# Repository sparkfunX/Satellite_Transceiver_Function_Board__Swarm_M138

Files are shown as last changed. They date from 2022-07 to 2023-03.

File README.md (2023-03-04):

SparkX Satellite Transceiver Function Board - Swarm M138
========================================

<p align="center">
  <a href="https://github.com/sparkfunX/Satellite_Transceiver_Function_Board__Swarm_M138/issues" alt="Issues">
    </a>
  <a href="https://github.com/sparkfunX/Satellite_Transceiver_Function_Board__Swarm_M138/actions" alt="Actions">
    </a>
  <a href="https://github.com/sparkfunX/Satellite_Transceiver_Function_Board__Swarm_M138/blob/main/LICENSE.md" alt="License">
    </a>
  <a href="https://twitter.com/intent/follow?screen_name=sparkfun">
    </a>
</p>

SparkX Satellite Transceiver Function Board - Swarm M138 (https://www.sparkfun.com/products/20107)

*[SparkX Satellite Transceiver Function Board - Swarm M138 (SPX-20107)](https://www.sparkfun.com/products/20107)*

The [SparkX Satellite Transceiver Function Board - Swarm M138 (SPX-20107)](https://www.sparkfun.com/products/20107) is an adapter which allows you to add Swarm Satellite connectivity
to your [MicroMod](https://www.sparkfun.com/micromod) project. It is designed to be plugged into the [MicroMod Main Board - Single](https://www.sparkfun.com/products/18575)
or [MicroMod Main Board - Double](https://www.sparkfun.com/products/18575). You can then install the Swarm M138 satellite modem and communicate using our dedicated 
[Swarm Satellite Arduino Library](https://github.com/sparkfun/SparkFun_Swarm_Satellite_Arduino_Library).

**Please note: the Swarm M138 modem is not included with the function board.** You will need to purchase the [Satellite Transceiver Breakout - Swarm M138 (SPX-19236)](https://www.sparkfun.com/products/19236)
separately to obtain the modem, antenna and ground plane.

Repository Contents
-------------------

* **[/docs](/docs/)** - Online documentation files
    * [board_files](/docs/board_files/) - Files for the product design
        * [Eagle design files](/docs/board_files/Satellite_Transceiver_Function_Board__Swarm_M138_x04.zip) (.zip)
        * [Schematic](/docs/board_files/Schematic.pdf) (.pdf)
        * [Dimensions](/docs/board_files/Dimensions.png) (.png)
    * [img/hookup_guide/](/docs/img/hookup_guide/) - Images for hookup guide documentation
* **[/Hardware](/Hardware/)** - Eagle design files (.brd, .sch)

Documentation
--------------
* **[Hookup Guide (mkdocs)](https://sparkfunx.github.io/Satellite_Transceiver_Function_Board__Swarm_M138/)** - Hookup guide for the SparkX Satellite Transceiver Function Board - Swarm M138 hosted by GitHub pages.

Product Versions
----------------
* [SPX-20107](https://www.sparkfun.com/products/20107) - Initial SparkX Release

License Information
-------------------

This product is _**open source**_! 

Please review the LICENSE.md file for license information. 

If you have any questions or concerns on licensing, please contact technical support on our [SparkFun forums](https://forum.sparkfun.com/viewforum.php?f=152).

Distributed as-is; no warranty is given.

- Your friends at SparkFun.

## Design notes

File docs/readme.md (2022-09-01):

This folder contains the assets and markdown files for the [SparkX Satellite Transceiver Function Board - Swarm M138 - Product Manual](https://sparkfunx.github.io/Satellite_Transceiver_Function_Board__Swarm_M138/) that are rendered with [mkdocs](https://www.mkdocs.org/).

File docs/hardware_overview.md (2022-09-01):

## Overview

The SparkX Satellite Transceiver Function Board - Swarm M138 is quite a simple board. The following is a summary of its features and functions:

* **`Power`** - Power for the Swarm M138 modem is drawn from the MicroMod **VCC** pins
    * The modem requires 3.0V<sub>Min</sub>, 5.0V<sub>Max</sub>
    * **VCC** will be 5.0V when the MicroMod Main Board is powered via USB-C
    * **VCC** will be between 3.6V and 4.2V when the MicroMod Main Board is drawing power from a LiPo battery
* **`High-Side Power Switch`** - Power for the Swarm M138 modem is connected via a MIC94064 High-Side Power Switch
    * By default, the modem power is turned off
    * Modem power can be enabled by pulling the **PWR_EN** pin high
        * **PWR_EN** is connected to the MicroMod Processor - the exact pin depends on which Main Board and Processor Board are being used. See the [table below](#example-pin-connection-table) for example pins
    * Modem power can be disabled by pulling the **PWR_EN** pin low or leaving it unconnected
    * The **EN** split pad jumper can be soldered closed to permanently enable modem power
* **`TX and RX`** - The M138 modem uses 3.3V serial (UART) to communicate at 115200 baud (8 data bits, 1 stop bit, no parity)
    * **TXO** and **RXI** are connected to UART pins on the MicroMod Processor
* **`GPIO1`** - The modem's **GPIO1** pin can perform several functions
    * **GPIO1** is connected to a GPIO pin on the MicroMod Processor - the exact pin depends on which Main Board and Processor Board are being used. See the [table below](#example-pin-connection-table) for example pins
    * **GPIO1** can be configured as a "wake from sleep mode" input
    * **GPIO1** can be configured as a "unread messages", "unsent messages" or "sleep mode active" output
    * When configured as an output, **GPIO1** is "open drain". A configurable pull-up resistor provides the high logic level
* **`TX/RX`** - The modem's TX/RX pin indicates if the modem is transmitting or receiving
    * **TX/RX** is connected to a GPIO pin on the MicroMod Processor - the exact pin depends on which Main Board and Processor Board are being used. See the [table below](#example-pin-connection-table) for example pins
    * **TX/RX** is high when the modem is transmitting, low when receiving
* **`EEPROM`** - Like all MicroMod Function Boards, a small EEPROM is provided
    * The Processor Board can read the EEPROM to discover which Function Boards are connected

## Board Images

<center>
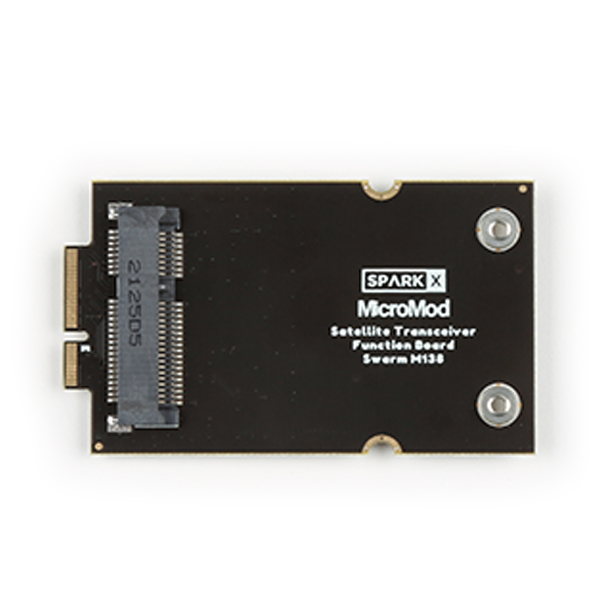
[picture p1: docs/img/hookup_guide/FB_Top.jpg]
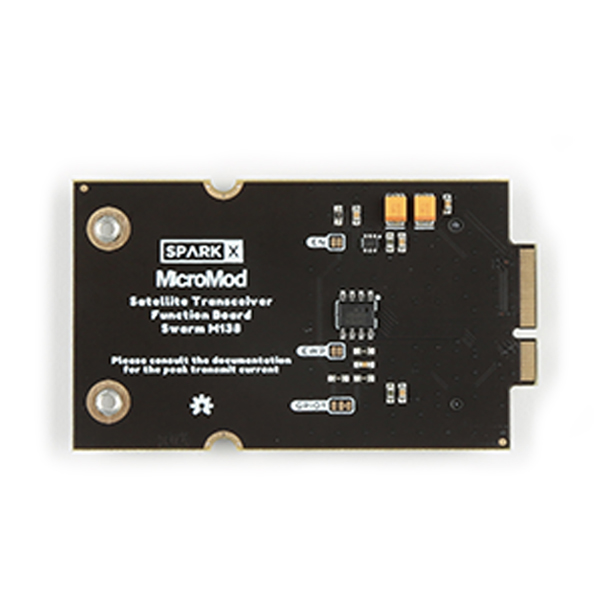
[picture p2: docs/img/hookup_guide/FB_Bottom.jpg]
  <br>
*Board images. (Click to enlarge)*
</center>

## Board Dimensions

The board dimensions are illustrated in the drawing below. The listed measurements are in mm. The two mounting holes and two stand-offs are compatible with M2.5 screws.

<center>
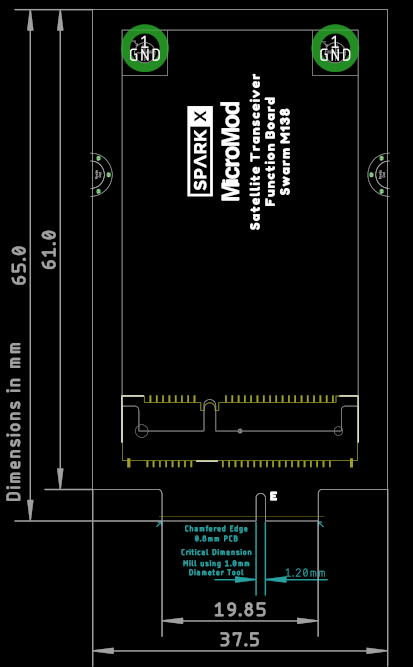
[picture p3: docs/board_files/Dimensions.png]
Board Dimensions
<br>
*Board dimensions. (Click to enlarge)*
</center>

## M.2 Connector Pinout

The pinout of the function board's M.2 edge connector (gold fingers) is defined in the following table.

Note that the M.2 connector pins on opposing sides are offset from each other as indicated by the bottom pins where it says "(Not Connected)".

There is no connection to pins that have a "-" under the primary function.

<table style="font-size:12.25px; width:100%">
    <tr>
        <th colspan="2" style="text-align:center; vertical-align:middle; min-width:2rem;" width="40.0%">
            Function
        </th>
        <th style="text-align:center; vertical-align:middle; min-width:1rem;" width="10.0%">
            Bottom<br>
            Pin
        </th>
        <th style="text-align:center; vertical-align:middle; min-width:1rem;" width="10.0%">
            Top<br>
            Pin
        </th>
        <th colspan="2" style="text-align:center; vertical-align:middle; min-width:2rem;" width="40.0%">
            Function
        </th>
    </tr>
    <tr>
        <td style="vertical-align:middle" align="center"></td>
        <td style="vertical-align:middle" align="center">(Not<br>Connected)</td>
        <td style="vertical-align:middle" align="center"></td>
        <td style="vertical-align:middle" align="center"><b>75</b></td>
        <td style="vertical-align:middle" align="center" bgcolor="#0000000"><font style="color: white; background: black;">GND</font></td>
        <td style="vertical-align:middle" align="center"></td>
    </tr>
    <tr>
        <td style="vertical-align:middle" align="center"></td>
        <td style="vertical-align:middle" align="center" bgcolor="#ea4335">VCC</td>
        <td style="vertical-align:middle" align="center"><b>74</b></td>
        <td style="vertical-align:middle" align="center"><b>73</b></td>
        <td style="vertical-align:middle" align="center" bgcolor="#ea4335">3.3V</td>
        <td style="vertical-align:middle" align="center"></td>
    </tr>
    <tr>
        <td style="vertical-align:middle" align="center"></td>
        <td style="vertical-align:middle" align="center" bgcolor="#ea4335">VCC</td>
        <td style="vertical-align:middle" align="center"><b>72</b></td>
        <td style="vertical-align:middle" align="center"><b>71</b></td>
        <td style="vertical-align:middle" align="center" bgcolor="#ea4335">PWR_EN</td>
        <td style="vertical-align:middle" align="center"><b>Power Enable</b><br>Pull high to<br>enable power</td>
    </tr>
    <tr>
        <td style="vertical-align:middle" align="center"></td>
        <td style="vertical-align:middle" align="center">-</td>
        <td style="vertical-align:middle" align="center"><b>70</b></td>
        <td style="vertical-align:middle" align="center"><b>69</b></td>
        <td style="vertical-align:middle" align="center">-</td>
        <td style="vertical-align:middle" align="center"></td>
    </tr>
    <tr>
        <td style="vertical-align:middle" align="center"></td>
        <td style="vertical-align:middle" align="center">-</td>
        <td style="vertical-align:middle" align="center"><b>68</b></td>
        <td style="vertical-align:middle" align="center"><b>67</b></td>
        <td style="vertical-align:middle" align="center">-</td>
        <td style="vertical-align:middle" align="center"></td>
    </tr>
    <tr>
        <td style="vertical-align:middle" align="center"></td>
        <td style="vertical-align:middle" align="center">-</td>
        <td style="vertical-align:middle" align="center"><b>66</b></td>
        <td style="vertical-align:middle" align="center"><b>65</b></td>
        <td style="vertical-align:middle" align="center">-</td>
        <td style="vertical-align:middle" align="center"></td>
    </tr>
    <tr>
        <td style="vertical-align:middle" align="center"></td>
        <td style="vertical-align:middle" align="center">-</td>
        <td style="vertical-align:middle" align="center"><b>64</b></td>
        <td style="vertical-align:middle" align="center"><b>63</b></td>
        <td style="vertical-align:middle" align="center">-</td>
        <td style="vertical-align:middle" align="center"></td>
    </tr>
    <tr>
        <td style="vertical-align:middle" align="center"></td>
        <td style="vertical-align:middle" align="center">-</td>
        <td style="vertical-align:middle" align="center"><b>62</b></td>
        <td style="vertical-align:middle" align="center"><b>61</b></td>
        <td style="vertical-align:middle" align="center">-</td>
        <td style="vertical-align:middle" align="center"></td>
    </tr>
    <tr>
        <td style="vertical-align:middle" align="center"></td>
        <td style="vertical-align:middle" align="center">-</td>
        <td style="vertical-align:middle" align="center"><b>60</b></td>
        <td style="vertical-align:middle" align="center"><b>59</b></td>
        <td style="vertical-align:middle" align="center">-</td>
        <td style="vertical-align:middle" align="center"></td>
    </tr>
    <tr>
        <td style="vertical-align:middle" align="center"></td>
        <td style="vertical-align:middle" align="center">-</td>
        <td style="vertical-align:middle" align="center"><b>58</b></td>
        <td style="vertical-align:middle" align="center"><b>57</b></td>
        <td style="vertical-align:middle" align="center">-</td>
        <td style="vertical-align:middle" align="center"></td>
    </tr>
    <tr>
        <td style="vertical-align:middle" align="center"></td>
        <td style="vertical-align:middle" align="center">-</td>
        <td style="vertical-align:middle" align="center"><b>56</b></td>
        <td style="vertical-align:middle" align="center"><b>55</b></td>
        <td style="vertical-align:middle" align="center">-</td>
        <td style="vertical-align:middle" align="center"></td>
    </tr>
    <tr>
        <td style="vertical-align:middle" align="center"></td>
        <td style="vertical-align:middle" align="center">-</td>
        <td style="vertical-align:middle" align="center"><b>54</b></td>
        <td style="vertical-align:middle" align="center"><b>53</b></td>
        <td style="vertical-align:middle" align="center">TX/RX</td>
        <td style="vertical-align:middle" align="center"><b>Modem State</b><br>Transmit (High)<br>Receive (Low)</td>
    </tr>
    <tr>
        <td style="vertical-align:middle" align="center"></td>
        <td style="vertical-align:middle" align="center">-</td>
        <td style="vertical-align:middle" align="center"><b>52</b></td>
        <td style="vertical-align:middle" align="center"><b>51</b></td>
        <td style="vertical-align:middle" align="center">-</td>
        <td style="vertical-align:middle" align="center"></td>
    </tr>
    <tr>
        <td style="vertical-align:middle" align="center"></td>
        <td style="vertical-align:middle" align="center">-</td>
        <td style="vertical-align:middle" align="center"><b>50</b></td>
        <td style="vertical-align:middle" align="center"><b>49</b></td>
        <td style="vertical-align:middle" align="center">-</td>
        <td style="vertical-align:middle" align="center"></td>
    </tr>
    <tr>
        <td style="vertical-align:middle" align="center"></td>
        <td style="vertical-align:middle" align="center">-</td>
        <td style="vertical-align:middle" align="center"><b>48</b></td>
        <td style="vertical-align:middle" align="center"><b>47</b></td>
        <td style="vertical-align:middle" align="center">GPIO1</td>
        <td style="vertical-align:middle" align="center"><b>Modem GPIO1</b><br>I/O pin</td>
    </tr>
    <tr>
        <td style="vertical-align:middle" align="center"></td>
        <td style="vertical-align:middle" align="center">-</td>
        <td style="vertical-align:middle" align="center"><b>46</b></td>
        <td style="vertical-align:middle" align="center"><b>45</b></td>
        <td style="vertical-align:middle" align="center" bgcolor="#0000000"><font style="color: white; background: black;">GND</font></td>
        <td style="vertical-align:middle" align="center"></td>
    </tr>
    <tr>
        <td style="vertical-align:middle" align="center"></td>
        <td style="vertical-align:middle" align="center">-</td>
        <td style="vertical-align:middle" align="center"><b>44</b></td>
        <td style="vertical-align:middle" align="center"><b>43</b></td>
        <td style="vertical-align:middle" align="center">-</td>
        <td style="vertical-align:middle" align="center"></td>
    </tr>
    <tr>
        <td style="vertical-align:middle" align="center"></td>
        <td style="vertical-align:middle" align="center">-</td>
        <td style="vertical-align:middle" align="center"><b>42</b></td>
        <td style="vertical-align:middle" align="center"><b>41</b></td>
        <td style="vertical-align:middle" align="center">-</td>
        <td style="vertical-align:middle" align="center"></td>
    </tr>
    <tr>
        <td style="vertical-align:middle" align="center">Write Protect</td>
        <td style="vertical-align:middle" align="center">EEPROM WP</td>
        <td style="vertical-align:middle" align="center"><b>40</b></td>
        <td style="vertical-align:middle" align="center"><b>39</b></td>
        <td style="vertical-align:middle" align="center" bgcolor="#0000000"><font style="color: white; background: black;">GND</font></td>
        <td style="vertical-align:middle" align="center"></td>
    </tr>
    <tr>
        <td style="vertical-align:middle" align="center"></td>
        <td style="vertical-align:middle" align="center">-</td>
        <td style="vertical-align:middle" align="center"><b>38</b></td>
        <td style="vertical-align:middle" align="center"><b>37</b></td>
        <td style="vertical-align:middle" align="center">-</td>
        <td style="vertical-align:middle" align="center"></td>
    </tr>
    <tr>
        <td style="vertical-align:middle" align="center"></td>
        <td style="vertical-align:middle" align="center">EEPROM A0</td>
        <td style="vertical-align:middle" align="center"><b>36</b></td>
        <td style="vertical-align:middle" align="center"><b>35</b></td>
        <td style="vertical-align:middle" align="center">-</td>
        <td style="vertical-align:middle" align="center"></td>
    </tr>
    <tr>
        <td style="vertical-align:middle" align="center"></td>
        <td style="vertical-align:middle" align="center">EEPROM A1</td>
        <td style="vertical-align:middle" align="center"><b>34</b></td>
        <td style="vertical-align:middle" align="center"><b>33</b></td>
        <td style="vertical-align:middle" align="center" bgcolor="#0000000"><font style="color: white; background: black;">GND</font></td>
        <td style="vertical-align:middle" align="center"></td>
    </tr>
    <tr>
        <td style="vertical-align:middle" align="center"></td>
        <td style="vertical-align:middle" align="center">EEPROM A2</td>
        <td style="vertical-align:middle" align="center"><b>32</b></td>
        <td style="vertical-align:middle" align="center"><b>31</b></td>
        <td style="vertical-align:middle" align="center">Module Key</td>
        <td style="vertical-align:middle" align="center"></td>
    </tr>
    <tr>
        <td style="vertical-align:middle" align="center"></td>
        <td style="vertical-align:middle" align="center">Module Key</td>
        <td style="vertical-align:middle" align="center"><b>30</b></td>
        <td style="vertical-align:middle" align="center"><b>29</b></td>
        <td style="vertical-align:middle" align="center">Module Key</td>
        <td style="vertical-align:middle" align="center"></td>
    </tr>
    <tr>
        <td style="vertical-align:middle" align="center"></td>
        <td style="vertical-align:middle" align="center">Module Key</td>
        <td style="vertical-align:middle" align="center"><b>28</b></td>
        <td style="vertical-align:middle" align="center"><b>27</b></td>
        <td style="vertical-align:middle" align="center">Module Key</td>
        <td style="vertical-align:middle" align="center"></td>
    </tr>
    <tr>
        <td style="vertical-align:middle" align="center"></td>
        <td style="vertical-align:middle" align="center">Module Key</td>
        <td style="vertical-align:middle" align="center"><b>26</b></td>
        <td style="vertical-align:middle" align="center"><b>25</b></td>
        <td style="vertical-align:middle" align="center">Module Key</td>
        <td style="vertical-align:middle" align="center"></td>
    </tr>
    <tr>
        <td style="vertical-align:middle" align="center"></td>
        <td style="vertical-align:middle" align="center">Module Key</td>
        <td style="vertical-align:middle" align="center"><b>24</b></td>
        <td style="vertical-align:middle" align="center"><b>23</b></td>
        <td style="vertical-align:middle" align="center">-</td>
        <td style="vertical-align:middle" align="center"></td>
    </tr>
    <tr>
        <td style="vertical-align:middle" align="center"></td>
        <td style="vertical-align:middle" align="center">-</td>
        <td style="vertical-align:middle" align="center"><b>22</b></td>
        <td style="vertical-align:middle" align="center"><b>21</b></td>
        <td style="vertical-align:middle" align="center">EEPROM SCL</td>
        <td style="vertical-align:middle" align="center"></td>
    </tr>
    <tr>
        <td style="vertical-align:middle" align="center"></td>
        <td style="vertical-align:middle" align="center">-</td>
        <td style="vertical-align:middle" align="center"><b>20</b></td>
        <td style="vertical-align:middle" align="center"><b>19</b></td>
        <td style="vertical-align:middle" align="center">EEPROM SDA</td>
        <td style="vertical-align:middle" align="center"></td>
    </tr>
    <tr>
        <td style="vertical-align:middle" align="center"></td>
        <td style="vertical-align:middle" align="center">-</td>
        <td style="vertical-align:middle" align="center"><b>18</b></td>
        <td style="vertical-align:middle" align="center"><b>17</b></td>
        <td style="vertical-align:middle" align="center">-</td>
        <td style="vertical-align:middle" align="center"></td>
    </tr>
    <tr>
        <td style="vertical-align:middle" align="center"></td>
        <td style="vertical-align:middle" align="center">-</td>
        <td style="vertical-align:middle" align="center"><b>16</b></td>
        <td style="vertical-align:middle" align="center"><b>15</b></td>
        <td style="vertical-align:middle" align="center" bgcolor="#4285f4">RXI</td>
        <td style="vertical-align:middle" align="center">Modem UART In</td>
    </tr>
    <tr>
        <td style="vertical-align:middle" align="center"></td>
        <td style="vertical-align:middle" align="center">-</td>
        <td style="vertical-align:middle" align="center"><b>14</b></td>
        <td style="vertical-align:middle" align="center"><b>13</b></td>
        <td style="vertical-align:middle" align="center" bgcolor="#4285f4">TXO</td>
        <td style="vertical-align:middle" align="center">Modem UART Out</td>
    </tr>
    <tr>
        <td style="vertical-align:middle" align="center"></td>
        <td style="vertical-align:middle" align="center">-</td>
        <td style="vertical-align:middle" align="center"><b>12</b></td>
        <td style="vertical-align:middle" align="center"><b>11</b></td>
        <td style="vertical-align:middle" align="center">-</td>
        <td style="vertical-align:middle" align="center"></td>
    </tr>
    <tr>
        <td style="vertical-align:middle" align="center"></td>
        <td style="vertical-align:middle" align="center">-</td>
        <td style="vertical-align:middle" align="center"><b>10</b></td>
        <td style="vertical-align:middle" align="center"><b>9</b></td>
        <td style="vertical-align:middle" align="center">-</td>
        <td style="vertical-align:middle" align="center"></td>
    </tr>
    <tr>
        <td style="vertical-align:middle" align="center"></td>
        <td style="vertical-align:middle" align="center" bgcolor="#0000000"><font style="color: white; background: black;">GND</font></td>
        <td style="vertical-align:middle" align="center"><b>8</b></td>
        <td style="vertical-align:middle" align="center"><b>7</b></td>
        <td style="vertical-align:middle" align="center">-</td>
        <td style="vertical-align:middle" align="center"></td>
    </tr>
    <tr>
        <td style="vertical-align:middle" align="center"></td>
        <td style="vertical-align:middle" align="center">-</td>
        <td style="vertical-align:middle" align="center"><b>6</b></td>
        <td style="vertical-align:middle" align="center"><b>5</b></td>
        <td style="vertical-align:middle" align="center">-</td>
        <td style="vertical-align:middle" align="center"></td>
    </tr>
    <tr>
        <td style="vertical-align:middle" align="center"></td>
        <td style="vertical-align:middle" align="center">-</td>
        <td style="vertical-align:middle" align="center"><b>4</b></td>
        <td style="vertical-align:middle" align="center"><b>3</b></td>
        <td style="vertical-align:middle" align="center">-</td>
        <td style="vertical-align:middle" align="center"></td>
    </tr>
    <tr>
        <td style="vertical-align:middle" align="center"></td>
        <td style="vertical-align:middle" align="center" bgcolor="#0000000"><font style="color: white; background: black;">GND</font></td>
        <td style="vertical-align:middle" align="center"><b>2</b></td>
        <td style="vertical-align:middle" align="center"><b>1</b></td>
        <td style="vertical-align:middle" align="center" bgcolor="#0000000"><font style="color: white; background: black;">GND</font></td>
        <td style="vertical-align:middle" align="center"></td>
    </tr>
</table>

*For more details, users can reference the [schematic](./board_files/Schematic.pdf).*

## Example Pin Connection Table

The pin connections depend on which [MicroMod](https://www.sparkfun.com/micromod) Main Board and Processor Board are being used.

The table below provides an example for the [Artemis Processor Board](https://www.sparkfun.com/products/16401) and the [Main Board - Double](https://www.sparkfun.com/products/18576).

<table  style="font-size:12.25px;width:100%">
    <tr>
        <th rowspan="2" style="text-align:center; vertical-align:middle; min-width:2rem;" width="40.0%">
            Satellite Function Board<br>
            Pin Name
        </th>
        <th rowspan="2" style="text-align:center; vertical-align:middle; min-width:1rem;" width="20.0%">
            Processor<br>
            I/O<br>
            Direction
        </th>
        <th colspan="2" style="text-align:center; vertical-align:middle;min-width:2rem;" width="40.0%">
            Main Board's<br>
            Processor Pin
        </th>
    </tr>
    <tr>
        <th style="text-align:center; vertical-align:middle; min-width:1rem;" width="20.0%">
            Slot 0
        </th>
        <th style="text-align:center; vertical-align:middle; min-width:1rem;" width="20.0%">
            Slot 1
        </th>
    </tr>
    <tr>
        <td style="vertical-align:middle" align="center" bgcolor="#ea4335">VCC</td>
        <td style="vertical-align:middle" align="center">Power</td>
        <td style="vertical-align:middle" align="center" bgcolor="#ea4335">VCC</td>
        <td style="vertical-align:middle" align="center" bgcolor="#ea4335">VCC</td>
    </tr>
    <tr>
        <td style="vertical-align:middle" align="center" bgcolor="#0000000"><font style="color: white; background: black;">GND</font></td>
        <td style="vertical-align:middle" align="center">Power</td>
        <td style="vertical-align:middle" align="center" bgcolor="#0000000"><font style="color: white; background: black;">GND</font></td>
        <td style="vertical-align:middle" align="center" bgcolor="#0000000"><font style="color: white; background: black;">GND</font></td>
    </tr>
    <tr>
        <td style="vertical-align:middle" align="center" bgcolor="#ea4335">PWR_EN</td>
        <td style="vertical-align:middle" align="center">O</td>
        <td style="vertical-align:middle" align="center">PWR_EN0<br>(SDIO_DATA2)</td>
        <td style="vertical-align:middle" align="center">PWR_EN1<br>(SDIO_DATA1)</td>
    </tr>
    <tr>
        <td style="vertical-align:middle" align="center" bgcolor="#4285f4">TXO</td>
        <td style="vertical-align:middle" align="center">I</td>
        <td style="vertical-align:middle" align="center" bgcolor="#4285f4">RX1</td>
        <td style="vertical-align:middle" align="center" bgcolor="#4285f4">RX2</td>
    </tr>
    <tr>
        <td style="vertical-align:middle" align="center" bgcolor="#4285f4">RXI</td>
        <td style="vertical-align:middle" align="center">O</td>
        <td style="vertical-align:middle" align="center" bgcolor="#4285f4">TX1</td>
        <td style="vertical-align:middle" align="center" bgcolor="#4285f4">TX2</td>
    </tr>
    <tr>
        <td style="vertical-align:middle" align="center">GPIO1</td>
        <td style="vertical-align:middle" align="center">I/O</td>
        <td style="vertical-align:middle" align="center">D0</td>
        <td style="vertical-align:middle" align="center">D1</td>
    </tr>
    <tr>
        <td style="vertical-align:middle" align="center">TX/RX</td>
        <td style="vertical-align:middle" align="center">I</td>
        <td style="vertical-align:middle" align="center">G0</td>
        <td style="vertical-align:middle" align="center">G5</td>
    </tr>
</table>

## Power Control (High-Side Power Switch)

Power for the Swarm M138 modem is drawn from the MicroMod **VCC** pins. The modem requires 3.0V<sub>Min</sub>, 5.0V<sub>Max</sub>.

**VCC** will be 5.0V when the MicroMod Main Board is powered via USB-C, and between 3.6V and 4.2V when the MicroMod Main Board is drawing power from a LiPo battery.

Power for the Swarm M138 modem is connected via a MIC94064 High-Side Power Switch.

<center>    
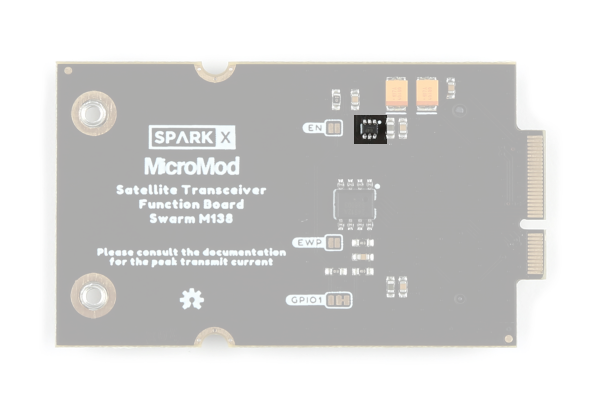
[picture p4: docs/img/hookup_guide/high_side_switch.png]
High-Side Power Switch
<br>
*The high-side power switch. (Click to enlarge)*
</center>

Modem power can be disabled by pulling the **PWR_EN** pin low or leaving it unconnected. By default, the modem power is turned off. 

Modem power can be enabled by pulling the **PWR_EN** pin high. **PWR_EN** is connected to the MicroMod Processor - the exact pin depends on which Main Board and Processor Board are being used.
See the [table above](#example-pin-connection-table) for example pins.

If required, the **EN** split pad jumper can be soldered closed to permanently enable modem power.

## Current Consumption

The modem's average current draw and peak draw during transmit depend on the supply voltage **VCC**.
For more details, please consult the [Satellite Transceiver Breakout - Swarm M138 - Hookup Guide](https://learn.sparkfun.com/tutorials/satellite-transceiver-breakout---swarm-m138---hookup-guide#current-draw).

When the **PWR_EN** pin is pulled low, the modem is powered off completely. The MIC94064 has a very low quiescent current of 2&micro;A.

## EEPROM

Like all MicroMod Function Boards, the board includes a small serial (I<sup>2</sup>C) EEPROM.
This can be programmed with a 'signature' to allow the Processor Board to detect which boards are installed.

<center>    
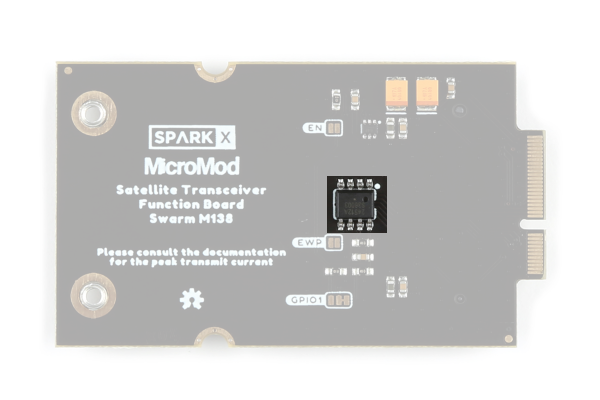
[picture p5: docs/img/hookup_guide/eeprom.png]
EEPROM
<br>
*The EEPROM. (Click to enlarge)*
</center>

By default, the EEPROM is write protected. The **WP** pin is pulled up by a 100K resistor. Soldering the **EWP** jumper closed will pull **WP** low, disabling write protection.

## Jumpers

!!! note
    <p>Never modified a jumper before? Check out our <a href="https://learn.sparkfun.com/tutorials/664">Jumper Pads and PCB Traces tutorial</a> for a quick introduction!</p>
    <p align="center">
        <a href="https://learn.sparkfun.com/tutorials/664">How to Work with Jumper Pads and PCB Traces<br>
        </a>
    </p>

There are three jumpers on the back of the board that can be used to modify how the board functions.

<center>
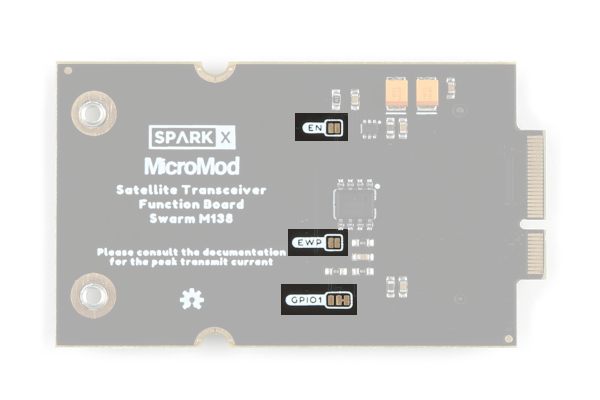
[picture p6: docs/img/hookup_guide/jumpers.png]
Jumpers
<br>
*The jumpers on the back of the function board. (Click to enlarge)*
</center>

* **GPIO1** - This is a double-jumper which connects pull-up and/or pull-down resistors to the modem's GPIO1 pin.
    * By default, the 100K pull-up resistor is connected so that a logic high is output when GPIO1 is in one of its "open drain" output modes
    * The pull-up can be disconnected by opening the closed half of the jumper
    * A 100K pull-down can be connected by closing the open half of the jumper
    * Both pull-up and pull-down can be connected to bias GPIO1 with 1.65V when it is configured as an analog input
* **EN** - This jumper can be closed to connect a 100K pull-up resistor to the high-side power switch's enable pin (**PWR_EN**)
    * Closing the jumper will cause the modem to be powered continuously
    * Some MicroMod Processor Boards do not have a GPIO pin connected to **PWR_EN**. If you are using one of these boards, solder the **EN** jumper closed to power the modem
* **EWP** - This jumper can be closed to disable the EEPROM write protection
    * By default, the EEPROM is write protected. The **WP** pin is pulled up by a 100K resistor
    * Soldering the **EWP** jumper closed will pull **WP** low, disabling write protection

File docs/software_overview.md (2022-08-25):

## Arduino IDE

!!! note
    For first-time users, who have never programmed before and are looking to use the Arduino IDE, we recommend beginning with the <a href="https://www.sparkfun.com/products/15631">SparkFun Inventor's Kit (SIK)</a>, which includes a simpler board like the <a href="https://www.sparkfun.com/products/11224">Arduino Uno</a> or <a href="https://www.sparkfun.com/products/15123">SparkFun RedBoard</a> and is designed to help users get started programming with the Arduino IDE.

Most users may already be familiar with the Arduino IDE and its use. However, for those of you who have never heard the name *Arduino* before, feel free to check out the [Arduino website](https://www.arduino.cc/en/Guide/HomePage). To get started with using the Arduino IDE, check out our tutorials below:

<table style="border-style:none">
    <tr>
        <td align="center">
            <a class="thumb" href="https://learn.sparkfun.com/tutorials/50">
                <center>What is an Arduino?
                </center>
                <h3 class="title">What is an Arduino?</h3>
            </a>
        </td>
        <td align="center">
            <a class="thumb" href="https://learn.sparkfun.com/tutorials/61">
                <center>Installing Arduino IDE
                </center>
                <h3 class="title">Installing Arduino IDE</h3>
            </a>
        </td>
        <td align="center">
            <a class="thumb" href="https://learn.sparkfun.com/tutorials/15">
                <center>Installing an Arduino Library
                </center>
                <h3 class="title">Installing an Arduino Library</h3>
            </a>
        </td>
        <td align="center">
            <a class="thumb" href="https://learn.sparkfun.com/tutorials/1265">
                <center>Installing Board Definitions in the Arduino IDE
                </center>
                <h3 class="title">Installing Board Definitions in the Arduino IDE</h3>
            </a>
        </td>
    </tr>
</table>

## Install Board Definition
Which board definition you need depends on which MicroMod Processor Board you are using:

<table style="border-style:none">
    <tr>
        <td align="center">
            <a class="thumb" href="https://learn.sparkfun.com/tutorials/1208">
                <center>MicroMod ESP32 Processor Board Hookup Guide?
                </center>
                <h3 class="title">MicroMod ESP32 Processor Board Hookup Guide</h3>
            </a>
        </td>
        <td align="center">
            <a class="thumb" href="https://learn.sparkfun.com/tutorials/1191">
                <center>MicroMod Artemis Processor Board Hookup Guide
                </center>
                <h3 class="title">MicroMod Artemis Processor Board Hookup Guide</h3>
            </a>
        </td>
        <td align="center">
            <a class="thumb" href="https://learn.sparkfun.com/tutorials/1207">
                <center>MicroMod SAMD51 Processor Board Hookup Guide
                </center>
                <h3 class="title">MicroMod SAMD51 Processor Board Hookup Guide</h3>
            </a>
        </td>
    </tr>
    <tr>
        <td align="center">
            <a class="thumb" href="https://learn.sparkfun.com/tutorials/1627">
                <center>MicroMod STM32 Processor Hookup Guide
                </center>
                <h3 class="title">MicroMod STM32 Processor Hookup Guide</h3>
            </a>
        </td>
        <td align="center">
            <a class="thumb" href="https://learn.sparkfun.com/tutorials/1266">
                <center>MicroMod Teensy Processor Hookup Guide
                </center>
                <h3 class="title">MicroMod Teensy Processor Hookup Guide</h3>
            </a>
        </td>
        <td align="center">
            <a class="thumb" href="https://learn.sparkfun.com/tutorials/1495">
                <center>MicroMod RP2040 Processor Board Hookup Guide
                </center>
                <h3 class="title">MicroMod RP2040 Processor Board Hookup Guide</h3>
            </a>
        </td>
    </tr>
    <tr>
        <center>
        <td align="center">
            <a class="thumb" href="https://learn.sparkfun.com/tutorials/1401">
                <center>MicroMod nRF52840 Processor Hookup Guide
                </center>
                <h3 class="title">MicroMod nRF52840 Processor Hookup Guide</h3>
            </a>
        </td>
        </center>
    </tr>
</table>

## SparkFun Swarm Satellite Arduino Library

Our [SparkFun Swarm Satellite Arduino Library](https://github.com/sparkfun/SparkFun_Swarm_Satellite_Arduino_Library) contains over 20 examples to get you up and running with Swarm Satellite and the M138 modem.

You can find the library through the Arduino IDE Library Manager. We recommend doing it this way, then you can update quickly and easily whenever we update the library.

* Click on **Tools\Manage Libraries...** to open the library manager
* In the search box, type **SparkFun Swarm**
* Click the **Install** button to install the library

You can also download the latest library manually if you want to:

<center>
[SparkFun Swarm Satellite Arduino Library (Zip)](https://github.com/sparkfun/SparkFun_Swarm_Satellite_Arduino_Library/archive/refs/heads/main.zip){ .md-button .md-button--primary }
</center>

## Adapting the Library Examples to the SparkX Satellite Transceiver Function Board - Swarm M138

The [SparkFun Swarm Satellite Arduino Library](https://github.com/sparkfun/SparkFun_Swarm_Satellite_Arduino_Library)
contains a full set of [tried and tested examples](https://github.com/sparkfun/SparkFun_Swarm_Satellite_Arduino_Library/tree/main/examples)
which will run on any of our MicroMod Processor Boards.

The code below is a stripped-down version of **Example3_getFirmwareVersion**. Copy and paste the code into a new window in the Arduino IDE.
Uncomment and adapt one of the ```#define swarmPowerEnablePin``` definitions to match your Main Board and Processor configuration:

```C++
#include <SparkFun_Swarm_Satellite_Arduino_Library.h> // http://librarymanager/All#SparkFun_Swarm_Satellite

SWARM_M138 mySwarm;

#define swarmSerial Serial1 // Use Serial1 to communicate with the modem. Change this if required.

// If you are using the Swarm Satellite Transceiver MicroMod Function Board:
//
// The Function Board has an onboard power switch which controls the power to the modem.
// The power is disabled by default.
// To enable the power, you need to pull the correct PWR_EN pin high.
//
// Uncomment and adapt a line to match your Main Board and Processor configuration:
//#define swarmPowerEnablePin A1 // MicroMod Main Board Single (DEV-18575) : with a Processor Board that supports A1 as an output
//#define swarmPowerEnablePin 39 // MicroMod Main Board Single (DEV-18575) : with e.g. the Teensy Processor Board using pin 39 (SDIO_DATA2) to control the power
//#define swarmPowerEnablePin 4  // MicroMod Main Board Single (DEV-18575) : with e.g. the Artemis Processor Board using pin 4 (SDIO_DATA2) to control the power
#define swarmPowerEnablePin G5 // MicroMod Main Board Double (DEV-18576) : Slot 0 with the ALT_PWR_EN0 set to G5<->PWR_EN0
//#define swarmPowerEnablePin G6 // MicroMod Main Board Double (DEV-18576) : Slot 1 with the ALT_PWR_EN1 set to G6<->PWR_EN1

void setup()
{
  // Swarm Satellite Transceiver MicroMod Function Board PWR_EN
  #ifdef swarmPowerEnablePin
  pinMode(swarmPowerEnablePin, OUTPUT); // Enable modem power 
  digitalWrite(swarmPowerEnablePin, HIGH);
  #endif

  Serial.begin(115200);

  if (mySwarm.begin(swarmSerial) == false) // Begin communication with the modem
  {
    Serial.println(F("Could not communicate with the modem. Please check the serial connections. Freezing..."));
    while (1)
      ;
  }

  char *firmwareVersion = new char[SWARM_M138_MEM_ALLOC_FV]; // Create storage for the configuration settings

  mySwarm.getFirmwareVersion(firmwareVersion); // Get the firmware version

  Serial.print(F("The firmware version is: "));
  Serial.println(firmwareVersion);

  delete[] firmwareVersion; // Free the storage
}

void loop()
{
  //Nothing to do here
}
```

Save the file and click on the **Upload** (arrow) button to upload the example onto your board.

Open **Tools\Serial Monitor** to see the modem firmware version.

Check that the baud rate is set to **115200**.

Enjoy your SpaceBees!

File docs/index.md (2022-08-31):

<p align="center">
  <a href="https://github.com/sparkfunX/Satellite_Transceiver_Function_Board__Swarm_M138/issues" alt="Issues">
    </a>
  <a href="https://github.com/sparkfunX/Satellite_Transceiver_Function_Board__Swarm_M138/actions" alt="Actions">
    </a>
  <a href="https://github.com/sparkfunX/Satellite_Transceiver_Function_Board__Swarm_M138/blob/main/LICENSE.md" alt="License">
    </a>
  <a href="https://twitter.com/intent/follow?screen_name=sparkfun">
    </a>
</p>

# SparkX Satellite Transceiver Function Board - Swarm M138

The [SparkX Satellite Transceiver Function Board - Swarm M138 (SPX-20107)](https://www.sparkfun.com/products/20107) is an adapter board which allows you to add Swarm Satellite connectivity
to your [MicroMod](https://www.sparkfun.com/micromod) project. It is designed to be plugged into the [MicroMod Main Board - Single](https://www.sparkfun.com/products/18575)
or [MicroMod Main Board - Double](https://www.sparkfun.com/products/18576). You can then install the Swarm M138 satellite modem and communicate using our dedicated 
[Swarm Satellite Arduino Library](https://github.com/sparkfun/SparkFun_Swarm_Satellite_Arduino_Library).

!!! note
    **The Swarm M138 modem is not included with the function board.** You will need to purchase the [Satellite Transceiver Breakout - Swarm M138 (SPX-19236)](https://www.sparkfun.com/products/19236) separately to obtain the modem, antenna and ground plane.

<center>
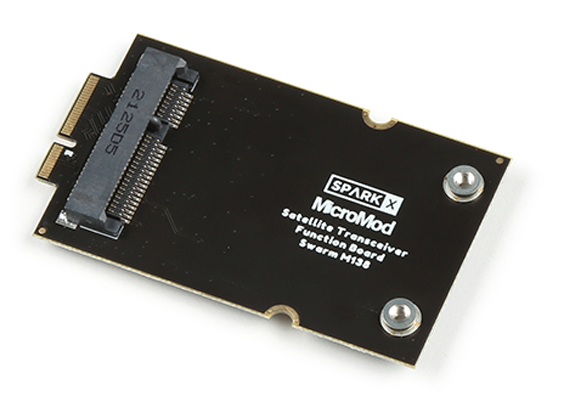
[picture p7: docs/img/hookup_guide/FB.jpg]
SparkX Swarm MicroMod Function Board (https://www.sparkfun.com/products/20107)

<br>
### [SparkX Swarm MicroMod Function Board (SPX-20107)](https://www.sparkfun.com/products/20107)
</center>

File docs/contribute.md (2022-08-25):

# Contribute: Help Fix our Mistake!

Spot something wrong? Feel free to contribute our open-source design and documentation. 

## Improve our Documentation

All of this documentation can be modified by you! Please help us make it better.

* These pages are contained in the [`docs` folder](https://github.com/sparkfunX/Satellite_Transceiver_Function_Board__Swarm_M138/tree/main/docs) of the [SparkX Satellite Transceiver Function Board - Swarm M138](https://github.com/sparkfunX/Satellite_Transceiver_Function_Board__Swarm_M138) repository.

### Submit a Correction

1. Fork this repo
2. Add your corrections or improvements to the markdown file
3. File a pull request with your changes, and enjoy making the ~~words~~ ~~worlds~~ world a better place.
    * Once received, the documentation specialist will automatically be notified.
    * We will review your suggested improvements to make sure they are correct and fit within our documentation standards.

## Improve our Hardware Design

All of our designs are open-source! Please help us make it better.

* Our board design files are contained in the [`Hardware` folder](https://github.com/sparkfunX/Satellite_Transceiver_Function_Board__Swarm_M138/tree/main/Hardware) of the [SparkX Satellite Transceiver Function Board - Swarm M138](https://github.com/sparkfunX/Satellite_Transceiver_Function_Board__Swarm_M138) repository. 

### Submit a Design Improvement

1. Fork this repo
2. Add your design improvements
3. File a pull request with your changes, and enjoy making the ~~words~~ ~~worlds~~ world a better place.
    * Once received, the engineer in charge of the original design will automatically be notified.
    * We will review your suggested improvements, if they are within our board design standards and meet our product design requirements, we will flag these changes for our next board revision. *(Please note, that even if your suggestion is accepted, these changes may not be immediate. We may have to cycle through our current product inventory first.)*

## Contributors

Let's provided some recognition to the contributors for this project!

GitHub Contributors Image
<br>


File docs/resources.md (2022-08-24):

# Resources

For more resources related to the SparkX Swarm MicroMod Function Board, check out the links listed here: 

* [Schematic](./board_files/Schematic.pdf) (PDF)
* [Eagle Files](./board_files/Satellite_Transceiver_Function_Board__Swarm_M138_x04.zip) (ZIP)
* [Board Dimensions](./board_files/Dimensions.png) (PNG)
* [SparkFun MicroMod](https://www.sparkfun.com/micromod)
* [Satellite Transceiver Breakout - Swarm M138](https://www.sparkfun.com/products/19236)
* [Swarm Satellite Transceiver Breakout - Swarm M138 - Hookup Guide](https://learn.sparkfun.com/tutorials/satellite-transceiver-breakout---swarm-m138---hookup-guide)
* [Modem Manual](https://cdn.sparkfun.com/assets/9/1/0/e/3/SwarmM138-Modem-Product-Manual.pdf)
* [Swarm Satellite Arduino Library](https://github.com/sparkfun/SparkFun_Swarm_Satellite_Arduino_Library)

Swarm also provides great resources for their satellite modem: 

* [How to register your Swarm M138 modem](https://swarm.space/registering-your-swarm-m138-modem/)
* [Swarm Account Login](https://bumblebee.hive.swarm.space/login)
* [Swarm Pass Checker](https://kube.tools.swarm.space/pass-checker/)
* [Swarm FAQs](https://swarm.space/frequently-asked-questions/)
* [Swarm Newsletter Sign-Up](https://swarm.space/contact/)
* [Swarm Website](https://swarm.space/)

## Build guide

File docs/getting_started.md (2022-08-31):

## Required Materials

To get started, users will need a few items. Now some users may have a few of these items, feel free to modify your cart accordingly.

* [Satellite Transceiver Function Board - Swarm M138](https://www.sparkfun.com/products/20107)
* [Satellite Transceiver Breakout - Swarm M138](https://www.sparkfun.com/products/19236)
* [SparkFun MicroMod Main Board - Single](https://www.sparkfun.com/products/18575)
* [SparkFun MicroMod Main Board - Double](https://www.sparkfun.com/products/18576)
* [SparkFun MicroMod Artemis Processor](https://www.sparkfun.com/products/16401)
* [SparkFun MicroMod ESP32 Processor](https://www.sparkfun.com/products/16781)
* [GPS/GNSS Magnetic Mount Antenna - 3m (SMA)](https://www.sparkfun.com/products/14986)
* [Interface Cable SMA to U.FL](https://www.sparkfun.com/products/9145)
* [Magnetic Mount SMA - 2m](https://www.sparkfun.com/products/19576)
* [SMA Male to SMA Female - 10m (RG174)](https://www.sparkfun.com/products/17495)
* [USB 3.1 Cable A to C - 3 Foot](https://www.sparkfun.com/products/14743) - The Main Board USB interface serves two purposes: it powers the board and allows users to upload programs. (*\*If your computer doesn't have a USB-A slot, then choose an appropriate cable or adapter.*)
* Computer with an operating system (OS) that is compatible with all the software installation requirements.

<table style="border-style:none">
    <tr>
        <td>
            <a href="https://www.sparkfun.com/products/20107">
                <center>Satellite Transceiver Function Board - Swarm M138</center>
                <h3 class="title">Satellite Transceiver Function Board - Swarm M138</h3>
            </a>
            SPX-20107
        </td>
        <td>
            <a class="thumb" href="https://www.sparkfun.com/products/19236">
                <center>Satellite Transceiver Breakout - Swarm M138
                </center>
                <h3 class="title">Satellite Transceiver Breakout - Swarm M138</h3>
            </a>
            SPX-19236
        </td>
    </tr>
    <tr>
        <td>
            <a href="https://www.sparkfun.com/products/18575">
                <center>SparkFun MicroMod Main Board - Single</center>
                <h3 class="title">SparkFun MicroMod Main Board - Single</h3>
            </a>
            DEV-18575
        </td>
        <td>
            <a href="https://www.sparkfun.com/products/18576">
                <center>SparkFun MicroMod Main Board - Double</center>
                <h3 class="title">SparkFun MicroMod Main Board - Double</h3>
            </a>
            DEV-18576
        </td>
    </tr>
</table>

## Li-Po Battery
<p>For mobile applications, users will want to pick up a <a href="https://www.sparkfun.com/categories/54">single-cell LiPo battery</a> from our catalog. Below, are a few available options:</p>

<table style="border-style:none">
    <tr>
        <td>
            <a href="https://www.sparkfun.com/products/13855">
                <center>Lithium Ion Battery - 2Ah</center>
                <h3 class="title">Lithium Ion Battery - 2Ah</h3>
            </a>
            PRT-13855
        </td>
        <td>
            <a class="thumb" href="https://www.sparkfun.com/products/13851">
                <center>Lithium Ion Battery - 400mAh
                </center>
                <h3 class="title">Lithium Ion Battery - 400mAh</h3>
            </a>
            PRT-13851
        </td>
        <td>
            <a class="thumb" href="https://www.sparkfun.com/products/13813">
                <center>Lithium Ion Battery - 1Ah
                </center>
                <h3 class="title">Lithium Ion Battery - 1Ah</h3>
            </a>
            PRT-13813
        </td>
    </tr>
</table>

## Jumper Modification
<p>To modify the jumpers, users will need <a href="https://www.sparkfun.com/categories/49">soldering equipment</a> and/or a <a href="https://www.sparkfun.com/categories/379">knife</a>.</p>

<table style="border-style:none">
    <tr>
        <td>
            <a href="https://www.sparkfun.com/products/9325">
                <center>Solder Lead Free - 100-gram Spool</center>
                <h3 class="title">Solder Lead Free - 100-gram Spool</h3>
            </a>
            TOL-09325
        </td>
        <td>
            <a class="thumb" href="https://www.sparkfun.com/products/14228">
                <center>Weller WLC100 Soldering Station
                </center>
                <h3 class="title">Weller WLC100 Soldering Station</h3>
            </a>
            TOL-14228
        </td>
        <td>
            <a class="thumb" href="https://www.sparkfun.com/products/14579">
                <center>Chip Quik No-Clean Flux Pen - 10mL
                </center>
                <h3 class="title">Chip Quik No-Clean Flux Pen - 10mL</h3>
            </a>
            TOL-14579
        </td>
        <td>
            <a class="thumb" href="https://www.sparkfun.com/products/9200">
                <center>Hobby Knife
                </center>
                <h3 class="title">Hobby Knife</h3>
            </a>
            TOL-09200
        </td>
    </tr>
</table>

!!! note
    <p>New to jumpter pads? Check out our <a href="https://learn.sparkfun.com/tutorials/664">Jumper Pads and PCB Traces Tutorial</a> for a quick introduction!</p>
    <p align="center">
        <a href="https://learn.sparkfun.com/tutorials/664">How to Work with Jumper Pads and PCB Traces<br>
        </a>
    </p>

## Suggested Reading

As a more professionally oriented product, we will skip over the more fundamental tutorials (i.e. [**Ohm's Law**](https://learn.sparkfun.com/tutorials/voltage-current-resistance-and-ohms-law) and [**What is Electricity?**](https://learn.sparkfun.com/tutorials/what-is-electricity)). However, below are a few tutorials that may help users familiarize themselves with various aspects of the board.

<table style="border-style:none">
    <tr>
        <center>
        <td align="center">
            <a href="https://learn.sparkfun.com/tutorials/satellite-transceiver-breakout---swarm-m138---hookup-guide">Satellite Transceiver Breakout - Swarm M138 - Hookup Guide<br>
            </a>
        </td>
        </center>
    </tr>
    <tr>
        <td align="center">
            <a href="https://learn.sparkfun.com/tutorials/61">Installing the Arduino IDE<br>
            </a>
        </td>
        <td align="center">
            <a href="https://learn.sparkfun.com/tutorials/1265">Installing Board Definitions in the Arduino IDE<br>
            </a>
        </td>
        <td align="center">
            <a href="https://learn.sparkfun.com/tutorials/12">Installing an Arduino Library<br>
            </a>
        </td>
    </tr>
    <tr>
        <td align="center">
            <a href="https://learn.sparkfun.com/tutorials/908">How to Install CH340 Drivers<br>
            </a>
        </td>
        <td align="center">
            <a href="https://learn.sparkfun.com/tutorials/5">How to Solder: Through-Hole Soldering<br>
            </a>
        </td>
        <td align="center">
            <a href="https://learn.sparkfun.com/tutorials/664">How to Work with Jumper Pads and PCB Traces<br>
            </a>
        </td>
    </tr>
    <tr>
        <td align="center">
            <a href="https://learn.sparkfun.com/tutorials/8">Serial Communication<br>
            </a>
        </td>
        <td align="center">
            <a href="https://learn.sparkfun.com/tutorials/89">Analog vs. Digital<br>
            </a>
        </td>
        <td align="center">
            <a href="https://learn.sparkfun.com/tutorials/51">Pulse Width Modulation<br>
            </a>
        </td>
    </tr>
    <tr>
        <td align="center">
            <a href="https://learn.sparkfun.com/tutorials/62">Logic Levels<br>
            </a>
        </td>
        <td align="center">
            <a href="https://learn.sparkfun.com/tutorials/82">I2C<br>
            </a>
        </td>
        <td align="center">
            <a href="https://learn.sparkfun.com/tutorials/16">Serial Peripheral Interface (SPI)<br>
            </a>
        </td>
    </tr>
</table>

<center>
<div align="center">
    <div style="top:5px;left:5px;background-color:Gray;position:relative">
        <div style="top:-5px;left:-5px;background-color:#ffffff;position:relative;border:1px solid black;">
            <a href="https://www.sparkfun.com/qwiic">Qwiic Connect System</a>
        </div>
    </div>
</div>
</center>

One of the new, advanced features of the MicroMod Main Boards is that they take advantage of the [Qwiic connect system](https://www.sparkfun.com/qwiic). We recommend familiarizing yourself with the **Logic Levels** and **I<sup>2</sup>C** tutorials.  Click on the banner above to learn more about [Qwiic products](https://www.sparkfun.com/qwiic).

<center>
    <iframe width="600" height="327" src="https://www.youtube.com/embed/x0RDEHqFIF8" title="SparkFun's Qwiic Connect System" frameborder="0" allow="accelerometer; autoplay; clipboard-write; encrypted-media; gyroscope; picture-in-picture" allowfullscreen></iframe>
</center>

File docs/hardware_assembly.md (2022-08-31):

## Step 1: Mount the SparkX Satellite Transceiver Function Board

To begin, the SparkX Satellite Transceiver Function Board needs to be mounted on your chosen [MicroMod](https://www.sparkfun.com/micromod) main board.
It is designed to be plugged into the [MicroMod Main Board - Single](https://www.sparkfun.com/products/18575)
or [MicroMod Main Board - Double](https://www.sparkfun.com/products/18576).

!!! note
    <p>If you have not already, make sure to check out the <a href="https://learn.sparkfun.com/tutorials/getting-started-with-micromod#hardware-hookup">Getting Started with MicroMod: Hardware Hookup</a> for information on inserting your Processor and Function Boards to the Main Board.</p>
    <p align="center">
        <a href="https://learn.sparkfun.com/tutorials/1189">Getting Started with MicroMod: Hardware Hookup<br>
        </a>
    </p>

Insert the function board at an angle into the M.2 connector. The board will stick up at an angle (at around 25°).

<center>
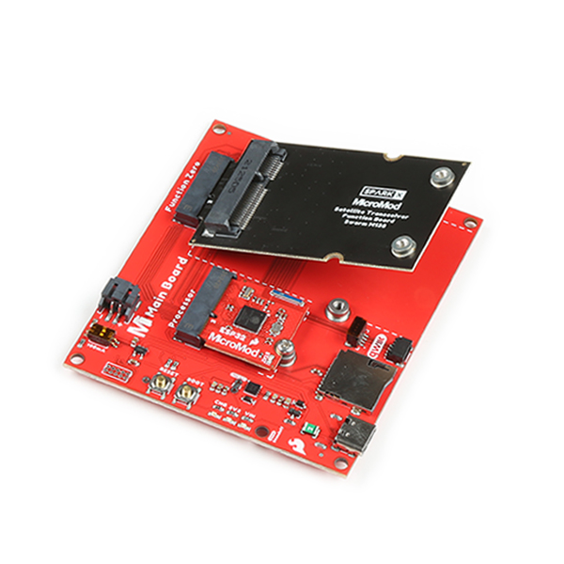
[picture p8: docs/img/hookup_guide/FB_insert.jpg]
<br>
*Inserting the function board. (Click to enlarge)*
</center>

Hold down the board, insert the screws, and start to tighten. Once the screws make contact with the circuit board, tighten each one just a little and then swap to the other.
By swapping between the two screws and tightening each one a little at a time, you can prevent the function board from 'walking' out of alignment.

!!! attention
    If you are unable to power up your M138 modem and communicate with it, it may be because the M.2 contacts (gold fingers) are slightly out of alignment. Remove the screws, remove the function board, re-insert it while pushing it gently over to one side, and replace the screws. If you are still unable to communicate with the modem, repeat the process and gently push to the other side as you re-insert the board. Tighten both screws a little at a time to prevent the board from 'walking' out of alignment.

<center>
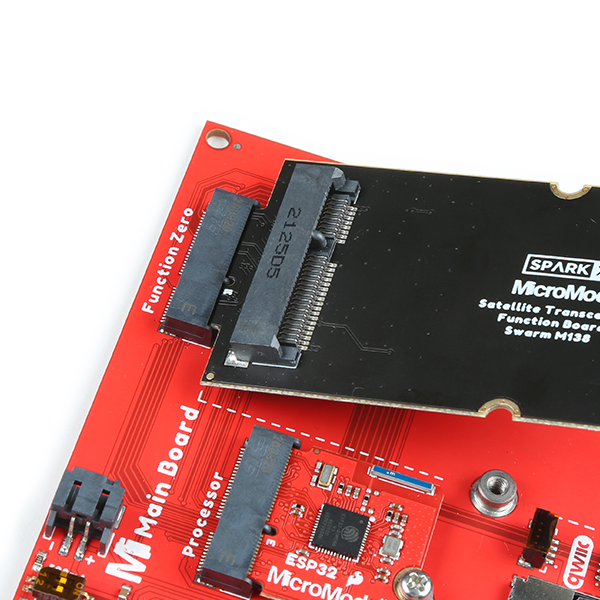
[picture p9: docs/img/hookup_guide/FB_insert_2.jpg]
<br>
*Inserting the function board. (Click to enlarge)*
</center>

## Step 2: Mount the Swarm M138 Modem

Now it is time to insert and secure the M138 modem.

Insert the modem at an angle into the M.2 connector. The modem will stick up at an angle (at around 25°).

<center>
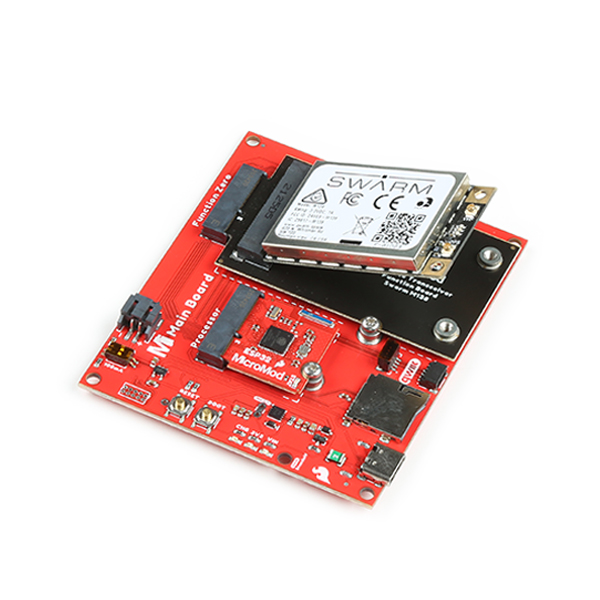
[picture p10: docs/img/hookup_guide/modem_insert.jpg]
Modem Insertion
<br>
*Inserting the modem. (Click to enlarge)*
</center>

Hold down the modem, insert the screws, and start to tighten. Once the screws make contact with the circuit board, tighten each one just a little and then swap to the other.
By swapping between the two and tightening each one a little at a time, you can prevent the modem from 'walking' out of alignment.

After securing the modem, your setup should look like the image below.

<center>
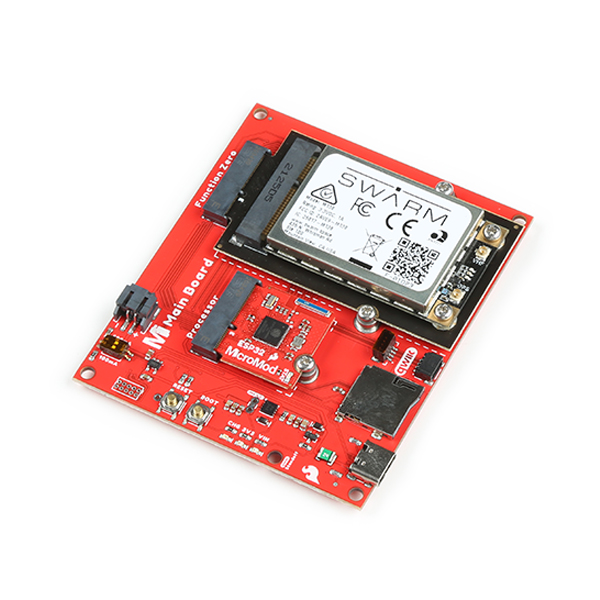
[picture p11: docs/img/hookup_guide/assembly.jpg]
Completed Assembly
<br>
*The function board and modem, assembled. (Click to enlarge)*
</center>

## Step 3: Attach the two u.FL antenna connections

The M138 modem requires two antennas: one for **VHF** (to communicate with the Swarm satellites) and a separate one for **GPS** (GNSS, for satellite location). Both are connected via u.FL.

Go ahead and attach both antenna connections. For your MicroMod project, you may find it useful to use u.FL-to-SMA adapter cables.
SMA connectors are much more robust than u.FL and can be mounted on your project enclosure ("bulkhead" connections).

!!! note
    <p>If you have not already, make sure to check out our <a href="https://learn.sparkfun.com/tutorials/three-quick-tips-about-using-ufl">Three Quick Tips About Using U.FL tutorial</a> for information on disconnecting and reconnecting the antenna connections.</p>
    <p align="center">
        <a href="https://learn.sparkfun.com/tutorials/845">Three Quick Tips About Using U.FL tutorial<br>
        </a>
    </p>

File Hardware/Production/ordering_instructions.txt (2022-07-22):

panel size, 128x137mm
PCB thickness, 0.8mm
number of layers, 2
bevel, Gold Fingers + 45° Finger Chamfered
soldermask color, Black
silkscreen color, White
oz copper, 1oz
finish, ENIG
stencils, top+bottom
pcs per panel, 6
min trace width, 0.1524mm / 0.0060in
min drill size, 0.3000mm / 0.0118in

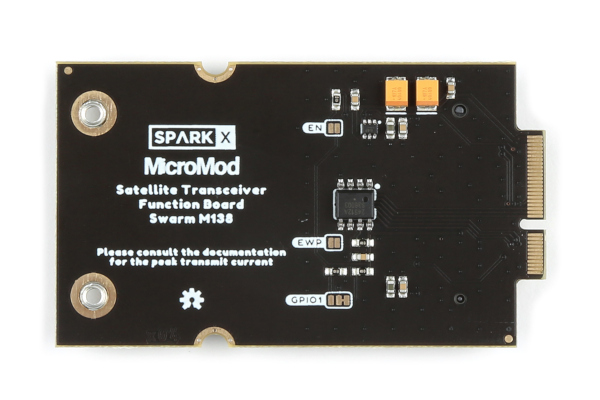
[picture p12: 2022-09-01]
docs/img/hookup_guide/FB_Bottom_Crop.jpg

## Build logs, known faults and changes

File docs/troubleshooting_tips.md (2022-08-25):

!!! note
    <p><span class="glyphicon glyphicon-question-sign" aria-hidden="true"></span> <strong>Not working as expected and need help? </strong></p>
    <p><a href="https://www.sparkfun.com/sparkx">SparkX</a> products are rapidly produced to bring you the most cutting edge technology as it becomes available. These products are tested but come with no guarantees. Live technical support is not available for SparkX products. Head on over to our <a href="https://forum.sparkfun.com/viewforum.php?f=123">forum</a> for support or to ask a question.<p>
    <center>
    [SparkX Forum](https://forum.sparkfun.com/viewforum.php?f=123){ .md-button .md-button--primary }
    </center>
    <p>You'll need a <a href="https://forum.sparkfun.com/ucp.php?mode=register">Forum Account</a> to search the product forums and post questions.<p>

## Power and Communication Issues

### PWR_EN

VCC power for the Swarm M138 modem is connected via a MIC94064 High-Side Power Switch:

* By default, the modem power is turned off
* Modem power can be enabled by pulling the **PWR_EN** pin high
    * **PWR_EN** is connected to the MicroMod Processor - the exact pin depends on which Main Board and Processor Board are being used. Please see the table in the **Product Manual - Hardware Overview** section for more details
* Modem power can be disabled by pulling the **PWR_EN** pin low or leaving it unconnected
* The **EN** split pad jumper can be soldered closed to permanently enable modem power

The modem has three very bright LEDs on it. These light up when power is applied. If the LEDs are lit, then **PWR_EN** is high and the high-side switch is enabled.

Some MicroMod Processor Boards do not have a GPIO pin connected to **PWR_EN**. If you are using one of these boards, solder the **EN** jumper closed to power the modem

### Power and UART Communication

If you are unable to power up your M138 modem and/or are unable to communicate with it, it may be because the M.2 contacts (gold fingers) are slightly out of alignment.

Remove the screws, remove the function board, re-insert it while pushing it gently over to one side, and replace the screws. If you are still unable to communicate with the modem, repeat the process and gently push to the other side as you re-insert the board. Tighten both screws a little at a time to prevent the board from 'walking' out of alignment. Please see the **Product Manual - Hardware Assembly** section for more details.

## Swarm Satellite Communication

Swarm have provided excellent advice about ensuring a good satellite signal. Please see this guest blog post for more details:

<center>
[Swarm x SparkFun](https://www.sparkfun.com/news/4860){ .md-button .md-button--primary }
</center>

You can find more useful information in the **Satellite Transceiver Breakout - Swarm M138 - Hookup Guide**:

<center>
[Satellite Transceiver Breakout - Swarm M138 - Hookup Guide](https://learn.sparkfun.com/tutorials/satellite-transceiver-breakout---swarm-m138---hookup-guide){ .md-button .md-button--primary }
</center>

**Example9_ReceiveTest** in our [Swarm Satellite Arduino Library](https://github.com/sparkfun/SparkFun_Swarm_Satellite_Arduino_Library) provides details on how to read the RSSI:

<center>
[Example9_ReceiveTest](https://github.com/sparkfun/SparkFun_Swarm_Satellite_Arduino_Library/blob/main/examples/Example9_ReceiveTest/Example9_ReceiveTest.ino){ .md-button .md-button--primary }
</center>

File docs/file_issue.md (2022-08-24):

# Did we make a mistake?

Spot something wrong? Please let us know. 

!!! attention
    [SparkX](https://www.sparkfun.com/sparkx) products are rapidly produced to bring you the most cutting edge technology as it becomes available. These products are tested but come with no guarantees. Live technical support is not available for SparkX products. Head on over to our [forum](https://forum.sparkfun.com/viewforum.php?f=123) for support or to ask a question.

## Discrepancies in the Documentation

All of this documentation can be modified by you! Please help us make it better.

* These pages are contained in the [`docs` folder](https://github.com/sparkfunX/Satellite_Transceiver_Function_Board__Swarm_M138/tree/main/docs) of the [SparkX Satellite Transceiver Function Board - Swarm M138](https://github.com/sparkfunX/Satellite_Transceiver_Function_Board__Swarm_M138) repository.

### Spot something wrong?
If a section of the documentation is incorrect, please [open an issue](https://github.com/sparkfunX/Satellite_Transceiver_Function_Board__Swarm_M138/issues) and let us know.

### Do you have a suggested correction?
1. Fork this repo
2. Add your corrections or improvements to the markdown file
3. File a pull request with your changes, and enjoy making the ~~words~~ ~~worlds~~ world a better place.
    * Once received, the documentation specialist will automatically be notified.
    * We will review your suggested improvements to make sure they are correct and fit within our documentation standards.

## Problems in the Hardware Design

All of our designs are open-source! Please help us make it better.

* Our board design files are contained in the [`Hardware` folder](https://github.com/sparkfunX/Satellite_Transceiver_Function_Board__Swarm_M138/tree/main/Hardware) of the [SparkX Satellite Transceiver Function Board - Swarm M138](https://github.com/sparkfunX/Satellite_Transceiver_Function_Board__Swarm_M138) repository. 

### Does something not make sense?
If part of the design is confusing, please [open an issue](https://github.com/sparkfunX/Satellite_Transceiver_Function_Board__Swarm_M138/issues) and let us know.

### Did we forget to include an important function of the board?
* Please keep in mind that we may intentionally exclude certain functions of the board to meet our product design requirements. *(For example, our Qwiic Micro boards are intended to fit on a small board layout and only use I<sup>2</sup>C communincation; therefore, we may not have the SPI and interrupt pins available for users.)*
* If part of the board's functionality is missing, please [open an issue](https://github.com/sparkfunX/Satellite_Transceiver_Function_Board__Swarm_M138/issues) and file a feature request.

### Do you wish to contribute directly to improving the board design?
1. Fork this repo
2. Add your design improvements
3. File a pull request with your changes, and enjoy making the ~~words~~ ~~worlds~~ world a better place.
    * Once received, the engineer in charge of the original design will automatically be notified.
    * We will review your suggested improvements, if they are within our board design standards and meet our product design requirements, we will flag these changes for our next board revision. *(Please note, that even if your suggestion is accepted, these changes may not be immediate. We may have to cycle through our current product inventory first.)*

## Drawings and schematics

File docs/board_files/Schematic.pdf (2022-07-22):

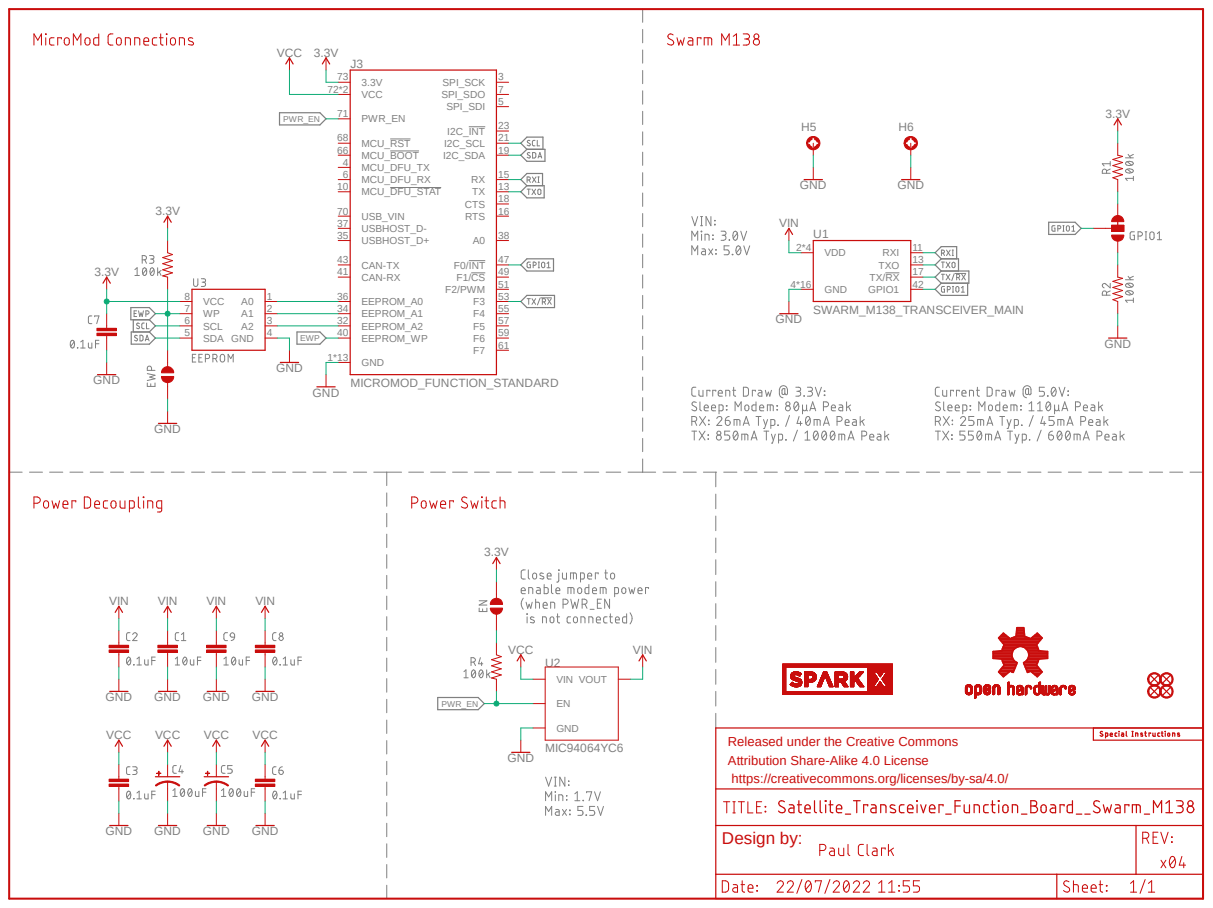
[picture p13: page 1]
GND; VCC; VIN; SWARM_M138_TRANSCEIVER_MAIN; MICROMOD_FUNCTION_STANDARD; VCC 3.3V; MIC94064YC6; GND 4*16; VDD 2*4; RXI 11; GPIO1 42 U1; GND 1*13; I2C_INT 23; SPI_SCK 3 SPI_SDO 7 SPI_SDI 5; USBHOST_D+ 35 USBHOST_D- 37; I2C_SCL 21 I2C_SDA 19; F0/INT 47; F2/PWM 51; VCC 72*2; USB_VIN 70; PWR_EN 71; RX 15 CTS 18 TX 13; RTS 16; EEPROM_A0 36 EEPROM_A1 34 EEPROM_A2 32 F7 61 EEPROM_WP 40; MCU_RST 68 MCU_BOOT 66 MCU_DFU_TX 4 MCU_DFU_RX 6; MCU_DFU_STAT 10 J3; GND 4; VCC 8; SCL 6 SDA 5; VOUT U2; PWR_EN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

CAN-RX 41 CAN-TX 43

TX/RX 17 TXO 13

Released under the Creative Commons
Attribution Share-Alike 4.0 License
https://creativecommons.org/licenses/by-sa/4.0/

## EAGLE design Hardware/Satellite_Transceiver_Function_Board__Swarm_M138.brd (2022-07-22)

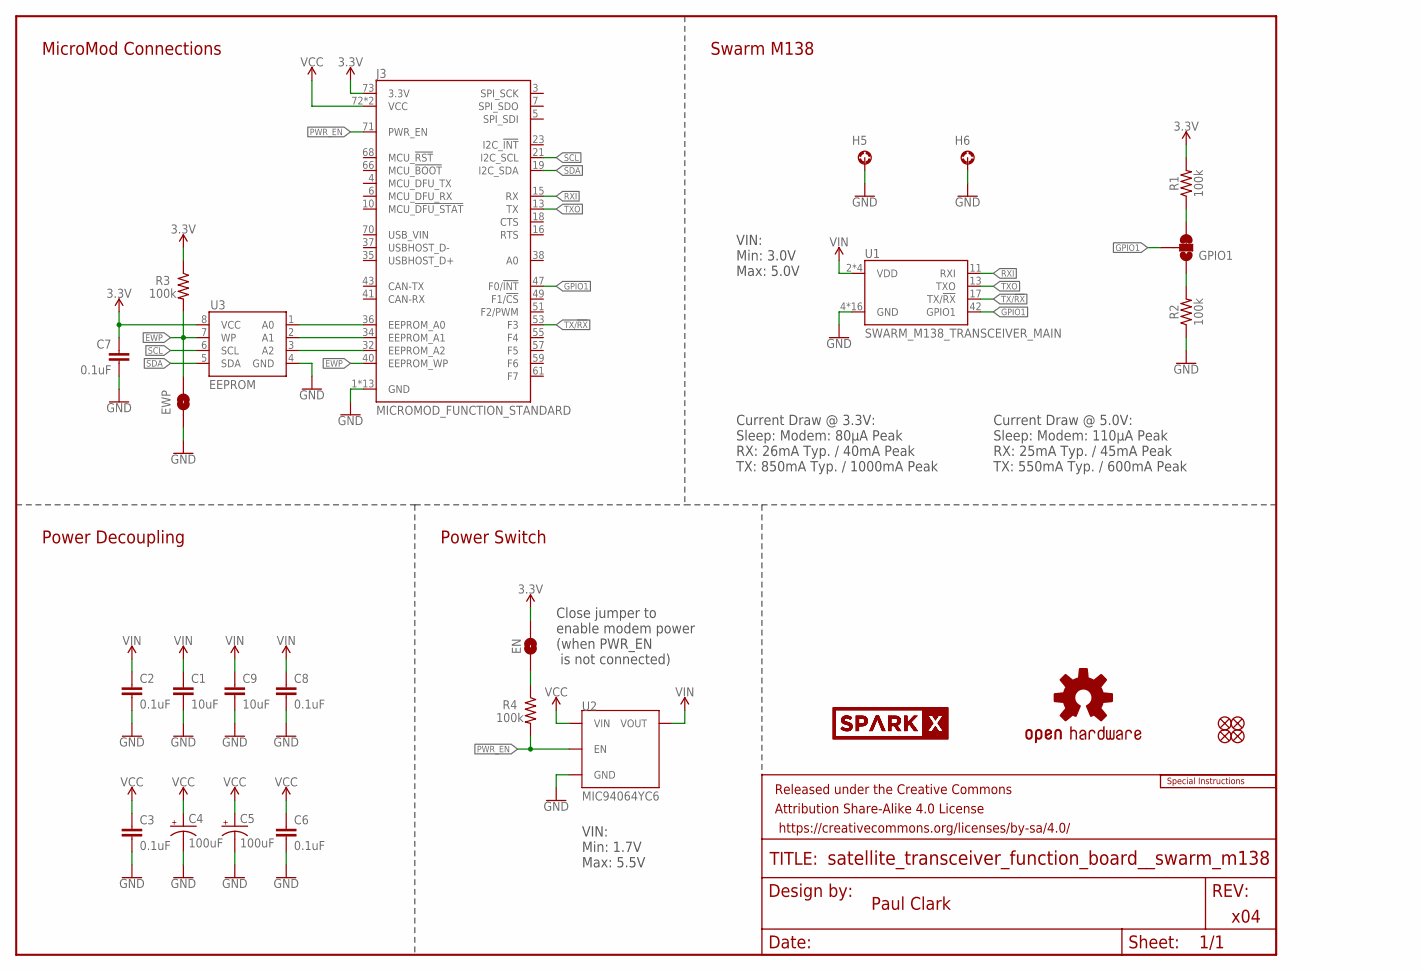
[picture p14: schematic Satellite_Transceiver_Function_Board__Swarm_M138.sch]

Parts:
C1, C9: 10uF; 0603
C2, C3, C6, C7, C8: 0.1uF; 0603
C4, C5: 100uF; EIA3528
EN: JUMPER-SMT_2_NO_SILK; SMT-JUMPER_2_NO_SILK
EWP: JUMPER-SMT_2_NO_SILK; SMT-JUMPER_2_NO_SILK
FD1, FD2, FD3, FD4: FIDUCIAL1X2; FIDUCIAL-1X2
FRAME1: FRAME-LETTER; CREATIVE_COMMONS
GPIO1: JUMPER-SMT_3_1-NC_TRACE_SILK; SMT-JUMPER_3_1-NC_TRACE_SILK
H5, H6: STAND-OFF-REFLOW-M2.5_1.5MM_TALL; STAND-OFF-REFLOW-M2.5
J3: MICROMOD_FUNCTION_STANDARD; M.2-CARD-E-22_FUNCTION_STANDARD
LOGO1: SPECIAL_INSTRUCTIONS-ORDERING; ORDERING_INSTRUCTIONS
LOGO2: OSHW-LOGOS; OSHW-LOGO-S
R1, R2, R3, R4: 100k; 0603
U1: SWARM_M138_TRANSCEIVER_MAIN; M.2-SWARM-M138-A
U2: MIC94064YC6; SC-70-6
U3: EEPROM; SO08
U$1, U$2: SPARKX-LOGO5; SPARKX-LARGE

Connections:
3.3V: C7.1, EN.2, J3.73 (3.3V), R1.2, R3.1, U3.8 (VCC)
A0: J3.36 (EEPROM_A0), U3.1 (A0)
A1: J3.34 (EEPROM_A1), U3.2 (A1)
A2: J3.32 (EEPROM_A2), U3.3 (A2)
EWP: EWP.2, J3.40 (EEPROM_WP), R3.2, U3.7 (WP)
GND: C1.2, C2.2, C3.2, C4.C (-), C5.C (-), C6.2, C7.2, C8.2, C9.2, EWP.1, H5.1, H6.1, J3.1 (GND), J3.2 (GND), J3.8 (GND), J3.33 (GND), J3.39 (GND), J3.45 (GND), J3.75 (GND), J3.GND1 (GND), J3.GND2 (GND), J3.GND3 (GND), J3.GND4 (GND), J3.GND5 (GND), J3.GND6 (GND), R2.1, U1.4 (GND), U1.9 (GND), U1.15 (GND), U1.18 (GND), U1.21 (GND), U1.26 (GND), U1.27 (GND), U1.29 (GND), U1.34 (GND), U1.35 (GND), U1.37 (GND), U1.40 (GND), U1.43 (GND), U1.50 (GND), U1.A1 (GND), U1.A2 (GND), U2.2 (GND), U2.5 (GND), U3.4 (GND)
GPIO1: GPIO1.2, J3.47 (F0/!INT!), U1.42 (GPIO1)
unnamed: EN.1, R4.1
unnamed: GPIO1.3, R1.1
unnamed: GPIO1.1, R2.2
PWR_EN: J3.71 (PWR_EN), R4.2, U2.3 (EN)
RXI: J3.15 (RX), U1.11 (RXI)
SCL: J3.21 (I2C_SCL), U3.6 (SCL)
SDA: J3.19 (I2C_SDA), U3.5 (SDA)
TX/!RX!: J3.53 (F3), U1.17 (TX/!RX!)
TXO: J3.13 (TX), U1.13 (TXO)
VCC: C3.1, C4.A (+), C5.A (+), C6.1, J3.72 (VCC), J3.74 (VCC), U2.4 (VIN)
VIN: C1.1, C2.1, C8.1, C9.1, U1.2 (VDD), U1.39 (VDD), U1.41 (VDD), U1.52 (VDD), U2.1 (VOUT)

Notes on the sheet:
x04
Paul Clark
Power Switch
Power Decoupling
Swarm M138
VIN: Min: 3.0V Max: 5.0V
Current Draw @ 3.3V: Sleep: Modem: 80µA Peak RX: 26mA Typ. / 40mA Peak TX: 850mA Typ. / 1000mA Peak
Current Draw @ 5.0V: Sleep: Modem: 110µA Peak RX: 25mA Typ. / 45mA Peak TX: 550mA Typ. / 600mA Peak
MicroMod Connections
VIN: Min: 1.7V Max: 5.5V
Close jumper to enable modem power (when PWR_EN is not connected)

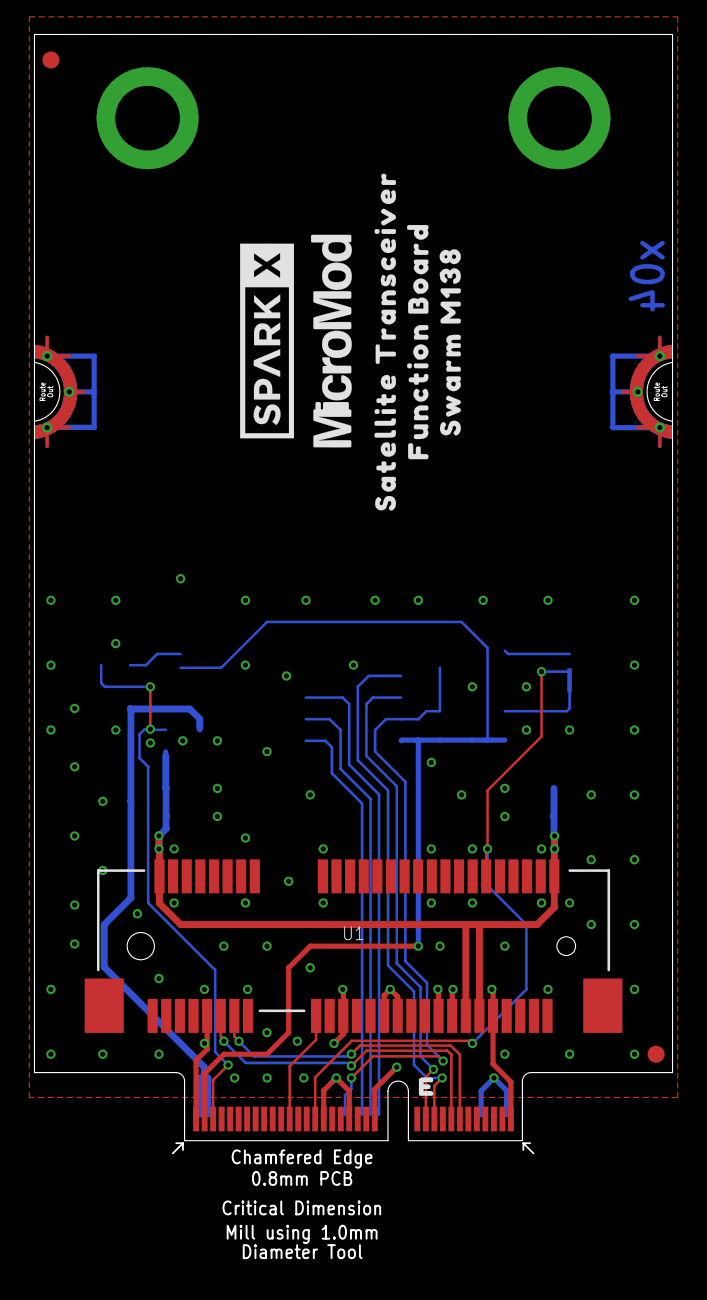
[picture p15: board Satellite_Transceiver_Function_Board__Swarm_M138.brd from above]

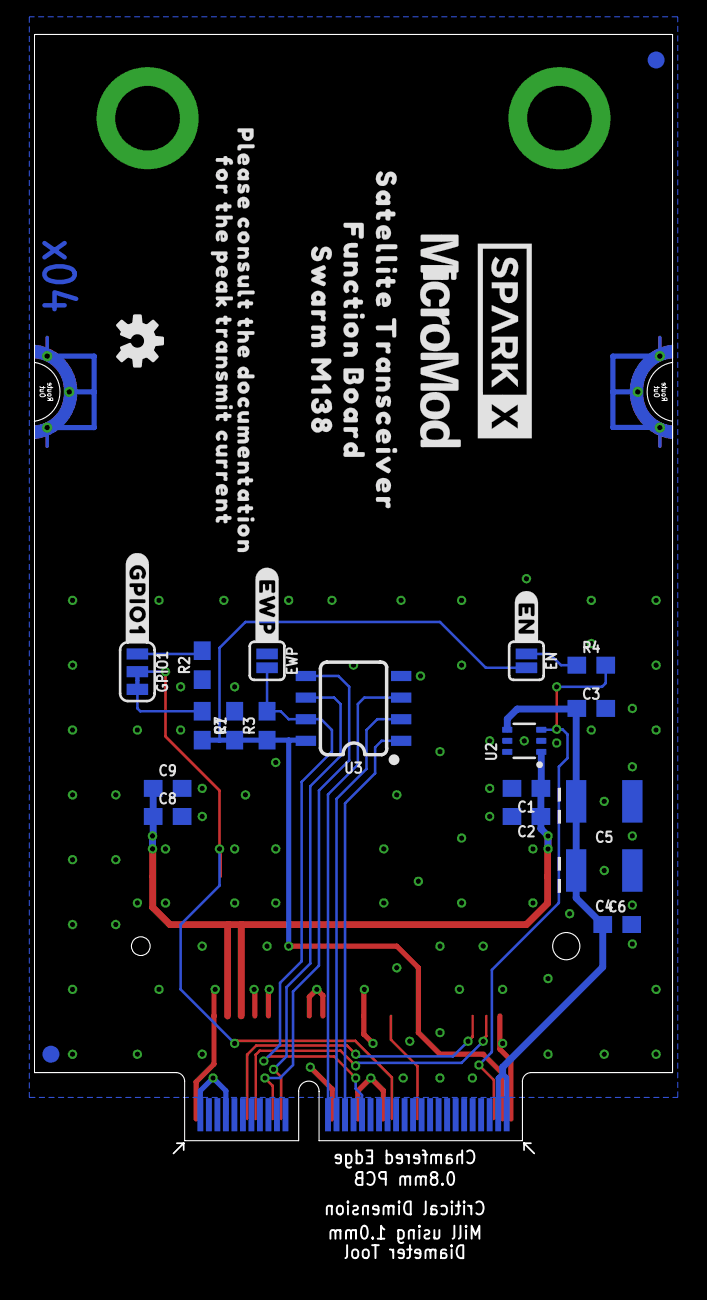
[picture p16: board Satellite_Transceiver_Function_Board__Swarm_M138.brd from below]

Board: 2 copper layers, 37.5 x 65.8 mm, 44 parts (31 on the bottom side), 18 nets.

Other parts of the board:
U$3, U$7: FUNCTION_BOARD0
U$4, U$5: SATELLITE_TRANSCEIVER0
U$6: PLEASE_CONSULT_THE_DOCUMENTATION0
U$8: #EWP#0
U$9, U$10: MICROMOD_LOGO_.5
U$11: #EN#0
U$19: #GPIO1#0
U$31: FOR_THE_PEAK_TRANSMIT_CURRENT1
U$40, U$41: SWARM_M1381

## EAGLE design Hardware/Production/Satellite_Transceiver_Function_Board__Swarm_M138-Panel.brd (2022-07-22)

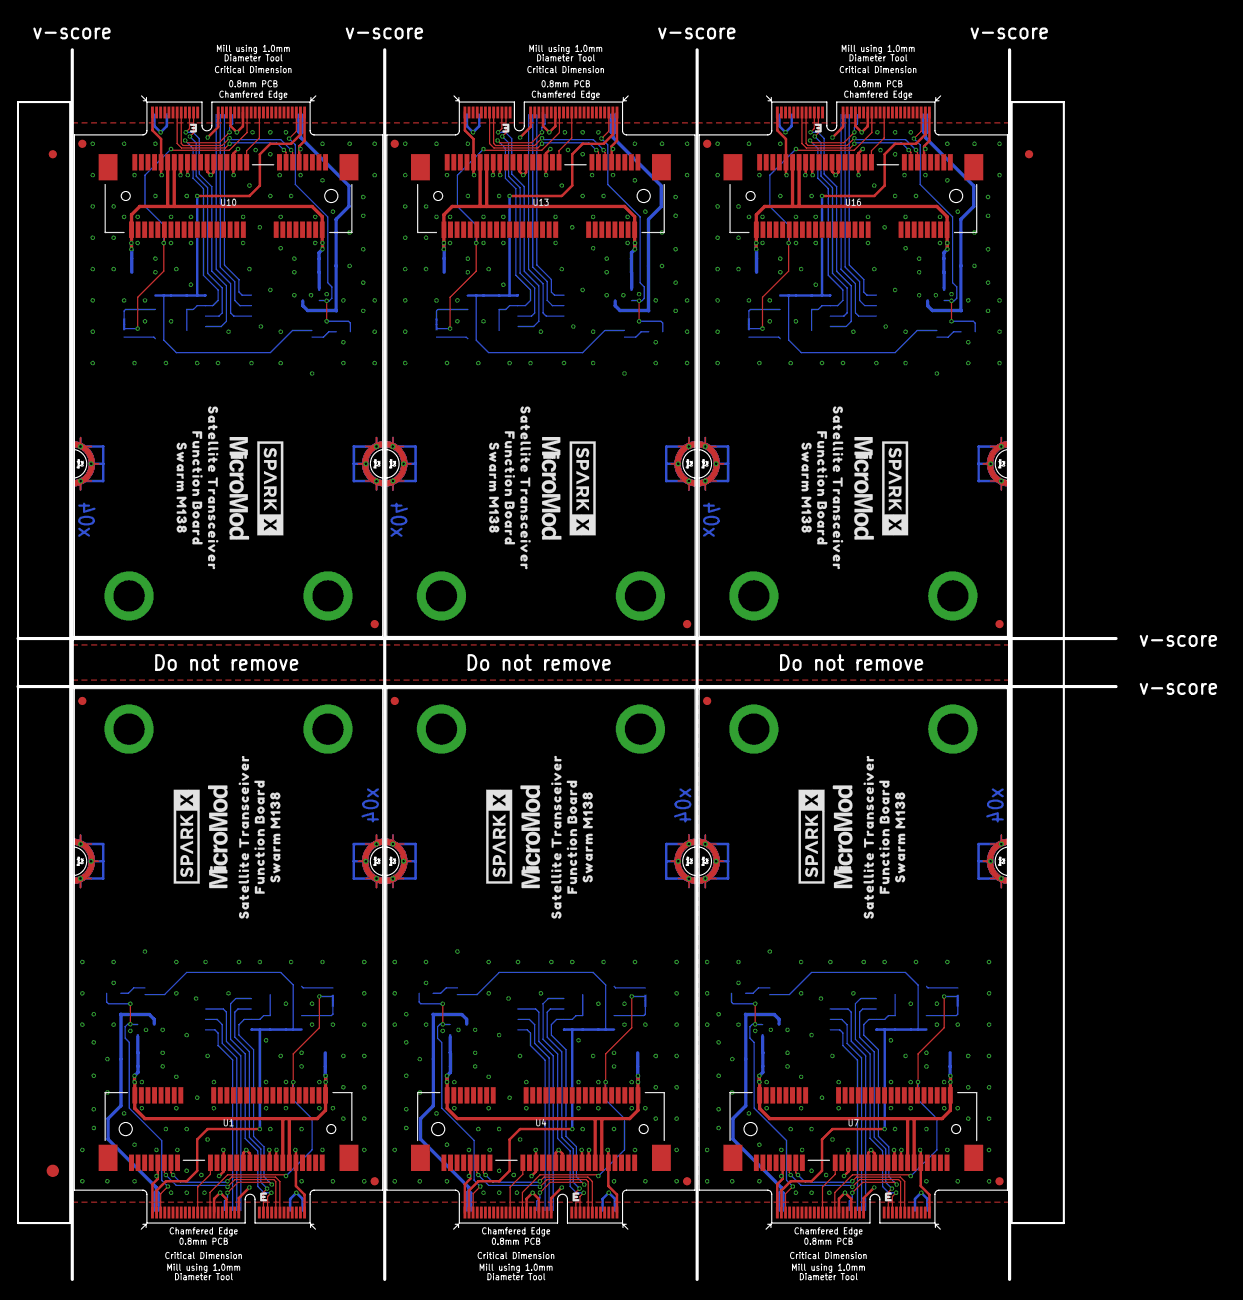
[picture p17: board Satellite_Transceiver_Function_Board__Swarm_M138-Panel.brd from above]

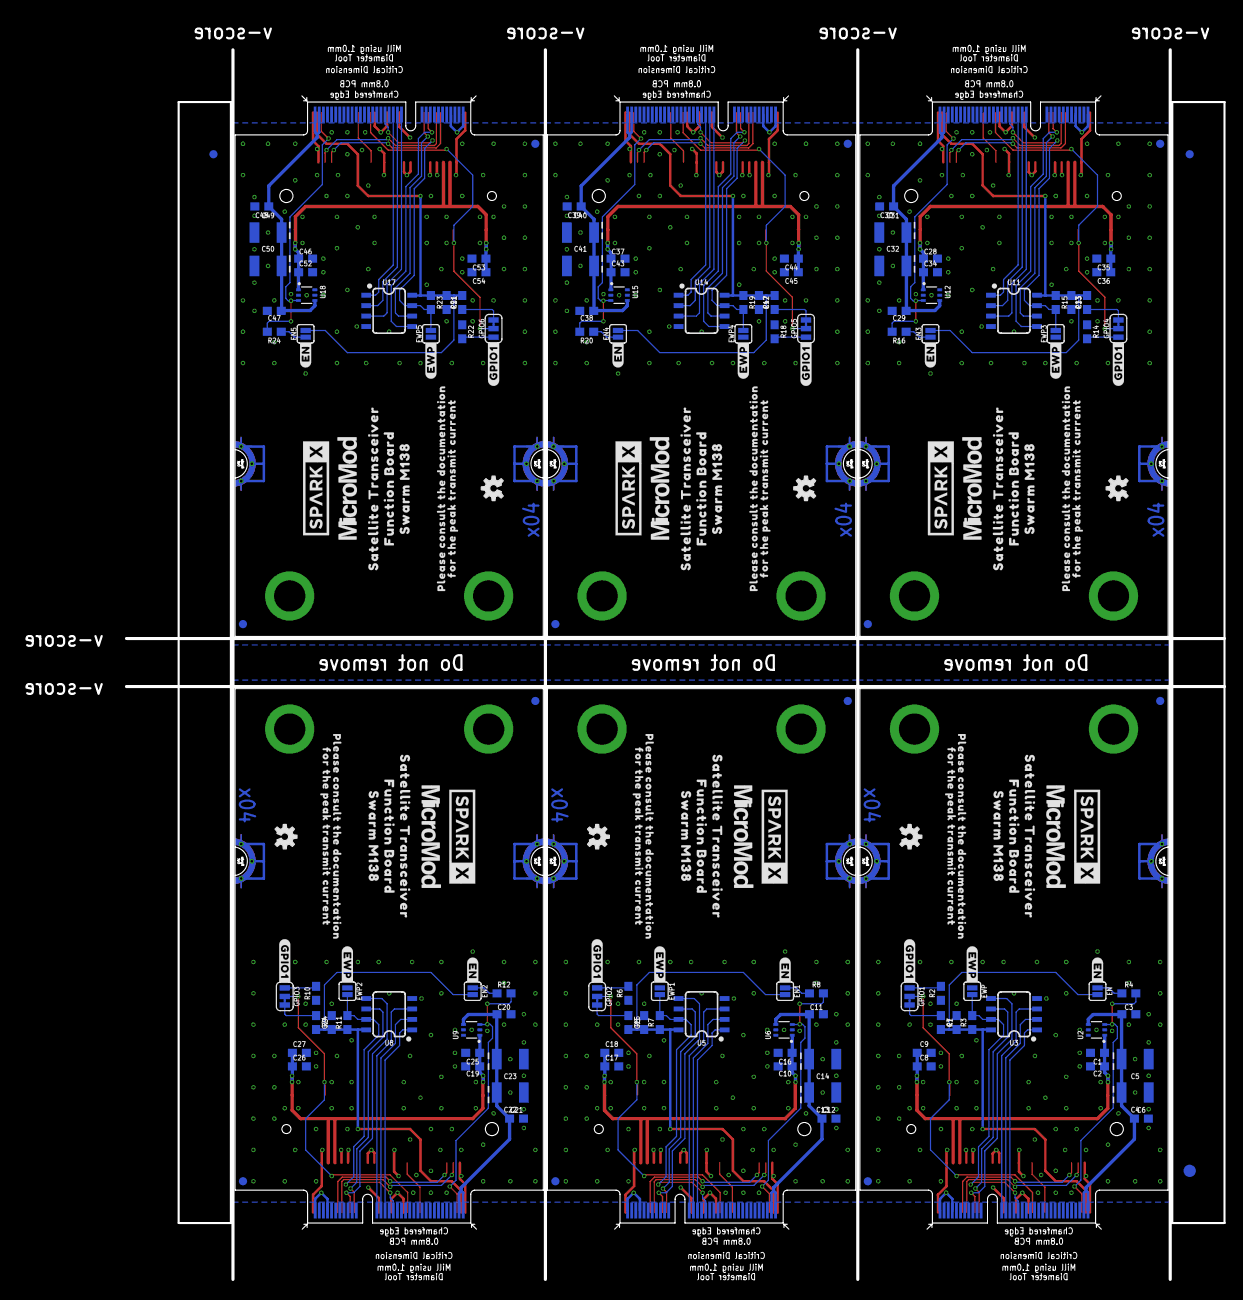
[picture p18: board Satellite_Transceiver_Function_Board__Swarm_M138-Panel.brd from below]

Board: 2 copper layers, 133.6 x 149.6 mm, 258 parts (189 on the bottom side), 108 nets.

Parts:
C1, C9, C16, C18, C25, C27, C34, C36, C43, C45, C52, C54: 10uF; 0603
C2, C3, C6, C7, C8, C10, C11, C12, C15, C17, C19, C20, C21, C24, C26, C28, C29, C30, C33, C35, C37, C38, C39, C42, C44, C46, C47, C48, C51, C53: 0.1uF; 0603
C4, C5, C13, C14, C22, C23, C31, C32, C40, C41, C49, C50: 100uF; EIA3528
E$1, E$2, E$3, E$4: FIDUCIAL-1X2
E$5, E$6: FIDUCIAL-1.5X3
EN, EN1, EN2, EN3, EN4, EN5: JUMPER-SMT_2_NO_SILK; SMT-JUMPER_2_NO_SILK
EWP, EWP1, EWP2, EWP3, EWP4, EWP5: JUMPER-SMT_2_NO_SILK; SMT-JUMPER_2_NO_SILK
FD1, FD2, FD3, FD4, FD5, FD6, FD7, FD8, FD9, FD10, FD11, FD12, FD13, FD14, FD15, FD16, FD17, FD18, FD19, FD20, FD21, FD22, FD23, FD24: FIDUCIAL1X2; FIDUCIAL-1X2
GPIO1, GPIO2, GPIO3, GPIO4, GPIO5, GPIO6: JUMPER-SMT_3_1-NC_TRACE_SILK; SMT-JUMPER_3_1-NC_TRACE_SILK
H1, H2, H3, H4, H5, H6, H7, H8, H9, H10, H11, H12: STAND-OFF-REFLOW-M2.5_1.5MM_TALL; STAND-OFF-REFLOW-M2.5
J1, J2, J3, J4, J5, J6: MICROMOD_FUNCTION_STANDARD; M.2-CARD-E-22_FUNCTION_STANDARD
LOGO1, LOGO2, LOGO3, LOGO4, LOGO5, LOGO6: OSHW-LOGOS; OSHW-LOGO-S
R1, R2, R3, R4, R5, R6, R7, R8, R9, R10, R11, R12, R13, R14, R15, R16, R17, R18, R19, R20, R21, R22, R23, R24: 100k; 0603
U1, U4, U7, U10, U13, U16: SWARM_M138_TRANSCEIVER_MAIN; M.2-SWARM-M138-A
U2, U6, U9, U12, U15, U18: MIC94064YC6; SC-70-6
U3, U5, U8, U11, U14, U17: EEPROM; SO08
U$1, U$2, U$12, U$13, U$28, U$29, U$46, U$47, U$61, U$62, U$76, U$77: SPARKX-LOGO5; SPARKX-LARGE
U$3, U$7, U$20, U$23, U$36, U$39, U$53, U$56, U$68, U$71, U$83, U$86: FUNCTION_BOARD0
U$4, U$5, U$21, U$22, U$37, U$38, U$54, U$55, U$69, U$70, U$84, U$85: SATELLITE_TRANSCEIVER0
U$6, U$17, U$34, U$51, U$66, U$81: PLEASE_CONSULT_THE_DOCUMENTATION0
U$8, U$24, U$42, U$57, U$72, U$87: #EWP#0
U$9, U$10, U$25, U$26, U$43, U$44, U$58, U$59, U$73, U$74, U$88, U$89: MICROMOD_LOGO_.5
U$11, U$27, U$45, U$60, U$75, U$90: #EN#0
U$14, U$19, U$30, U$48, U$63, U$78: #GPIO1#0
U$15, U$16, U$32, U$33, U$40, U$41, U$49, U$50, U$64, U$65, U$79, U$80: SWARM_M1381
U$18, U$31, U$35, U$52, U$67, U$82: FOR_THE_PEAK_TRANSMIT_CURRENT1

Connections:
3.3V: C7.1, EN.2, J3.73, R1.2, R3.1, U3.8
3.3V1: C15.1, EN1.2, J1.73, R5.2, R7.1, U5.8
3.3V2: C24.1, EN2.2, J2.73, R9.2, R11.1, U8.8
3.3V3: C33.1, EN3.2, J4.73, R13.2, R15.1, U11.8
3.3V4: C42.1, EN4.2, J5.73, R17.2, R19.1, U14.8
3.3V5: C51.1, EN5.2, J6.73, R21.2, R23.1, U17.8
A0: J3.36, U3.1
A1: J3.34, U3.2
A2: J3.32, U3.3
A3: J1.36, U5.1
A4: J1.32, U5.3
A5: J1.34, U5.2
A6: J2.36, U8.1
A7: J2.32, U8.3
A8: J2.34, U8.2
A9: J4.36, U11.1
A10: J4.32, U11.3
A11: J4.34, U11.2
A12: J5.36, U14.1
A13: J5.32, U14.3
A14: J5.34, U14.2
A15: J6.36, U17.1
A16: J6.32, U17.3
A17: J6.34, U17.2
EWP: EWP.2, J3.40, R3.2, U3.7
EWP1: EWP1.2, J1.40, R7.2, U5.7
EWP2: EWP2.2, J2.40, R11.2, U8.7
EWP3: EWP3.2, J4.40, R15.2, U11.7
EWP4: EWP4.2, J5.40, R19.2, U14.7
EWP5: EWP5.2, J6.40, R23.2, U17.7
GND: C1.2, C2.2, C3.2, C4.C, C5.C, C6.2, C7.2, C8.2, C9.2, EWP.1, H5.1, H6.1, J3.1, J3.2, J3.8, J3.33, J3.39, J3.45, J3.75, J3.GND1, J3.GND2, J3.GND3, J3.GND4, J3.GND5, J3.GND6, R2.1, U1.4, U1.9, U1.15, U1.18, U1.21, U1.26, U1.27, U1.29, U1.34, U1.35, U1.37, U1.40, U1.43, U1.50, U1.A1, U1.A2, U2.2, U2.5, U3.4
GND1: C10.2, C11.2, C12.2, C13.C, C14.C, C15.2, C16.2, C17.2, C18.2, EWP1.1, H1.1, H2.1, J1.1, J1.2, J1.8, J1.33, J1.39, J1.45, J1.75, J1.GND1, J1.GND2, J1.GND3, J1.GND4, J1.GND5, J1.GND6, R6.1, U4.4, U4.9, U4.15, U4.18, U4.21, U4.26, U4.27, U4.29, U4.34, U4.35, U4.37, U4.40, U4.43, U4.50, U4.A1, U4.A2, U5.4, U6.2, U6.5
GND2: C19.2, C20.2, C21.2, C22.C, C23.C, C24.2, C25.2, C26.2, C27.2, EWP2.1, H3.1, H4.1, J2.1, J2.2, J2.8, J2.33, J2.39, J2.45, J2.75, J2.GND1, J2.GND2, J2.GND3, J2.GND4, J2.GND5, J2.GND6, R10.1, U7.4, U7.9, U7.15, U7.18, U7.21, U7.26, U7.27, U7.29, U7.34, U7.35, U7.37, U7.40, U7.43, U7.50, U7.A1, U7.A2, U8.4, U9.2, U9.5
GND3: C28.2, C29.2, C30.2, C31.C, C32.C, C33.2, C34.2, C35.2, C36.2, EWP3.1, H7.1, H8.1, J4.1, J4.2, J4.8, J4.33, J4.39, J4.45, J4.75, J4.GND1, J4.GND2, J4.GND3, J4.GND4, J4.GND5, J4.GND6, R14.1, U10.4, U10.9, U10.15, U10.18, U10.21, U10.26, U10.27, U10.29, U10.34, U10.35, U10.37, U10.40, U10.43, U10.50, U10.A1, U10.A2, U11.4, U12.2, U12.5
GND4: C37.2, C38.2, C39.2, C40.C, C41.C, C42.2, C43.2, C44.2, C45.2, EWP4.1, H9.1, H10.1, J5.1, J5.2, J5.8, J5.33, J5.39, J5.45, J5.75, J5.GND1, J5.GND2, J5.GND3, J5.GND4, J5.GND5, J5.GND6, R18.1, U13.4, U13.9, U13.15, U13.18, U13.21, U13.26, U13.27, U13.29, U13.34, U13.35, U13.37, U13.40, U13.43, U13.50, U13.A1, U13.A2, U14.4, U15.2, U15.5
GND5: C46.2, C47.2, C48.2, C49.C, C50.C, C51.2, C52.2, C53.2, C54.2, EWP5.1, H11.1, H12.1, J6.1, J6.2, J6.8, J6.33, J6.39, J6.45, J6.75, J6.GND1, J6.GND2, J6.GND3, J6.GND4, J6.GND5, J6.GND6, R22.1, U16.4, U16.9, U16.15, U16.18, U16.21, U16.26, U16.27, U16.29, U16.34, U16.35, U16.37, U16.40, U16.43, U16.50, U16.A1, U16.A2, U17.4, U18.2, U18.5
GPIO1: GPIO1.2, J3.47, U1.42
GPIO2: GPIO2.2, J1.47, U4.42
GPIO3: GPIO3.2, J2.47, U7.42
GPIO4: GPIO4.2, J4.47, U10.42
GPIO5: GPIO5.2, J5.47, U13.42
GPIO6: GPIO6.2, J6.47, U16.42
unnamed: EN.1, R4.1
unnamed: GPIO2.3, R5.1
unnamed: GPIO2.1, R6.2
unnamed: EN1.1, R8.1
unnamed: GPIO3.3, R9.1
unnamed: GPIO3.1, R10.2
unnamed: EN2.1, R12.1
unnamed: GPIO4.3, R13.1
unnamed: GPIO4.1, R14.2
unnamed: EN3.1, R16.1
unnamed: GPIO5.3, R17.1
unnamed: GPIO5.1, R18.2
unnamed: EN4.1, R20.1
unnamed: GPIO1.3, R1.1
unnamed: GPIO6.3, R21.1
unnamed: GPIO1.1, R2.2
unnamed: GPIO6.1, R22.2
unnamed: EN5.1, R24.1
PWR_EN: J3.71, R4.2, U2.3
PWR_EN1: J1.71, R8.2, U6.3
PWR_EN2: J2.71, R12.2, U9.3
PWR_EN3: J4.71, R16.2, U12.3
PWR_EN4: J5.71, R20.2, U15.3
PWR_EN5: J6.71, R24.2, U18.3
RXI: J3.15, U1.11
RXI1: J1.15, U4.11
RXI2: J2.15, U7.11
RXI3: J4.15, U10.11
RXI4: J5.15, U13.11
RXI5: J6.15, U16.11
SCL: J3.21, U3.6
SCL1: J1.21, U5.6
SCL2: J2.21, U8.6
SCL3: J4.21, U11.6
SCL4: J5.21, U14.6
SCL5: J6.21, U17.6
SDA: J3.19, U3.5
SDA1: J1.19, U5.5
SDA2: J2.19, U8.5
SDA3: J4.19, U11.5
SDA4: J5.19, U14.5
SDA5: J6.19, U17.5
TX/!RX!: J3.53, U1.17
TX/!RX!1: J1.53, U4.17
TX/!RX!2: J2.53, U7.17
TX/!RX!3: J4.53, U10.17
TX/!RX!4: J5.53, U13.17
TX/!RX!5: J6.53, U16.17
TXO: J3.13, U1.13
TXO1: J1.13, U4.13
TXO2: J2.13, U7.13
TXO3: J4.13, U10.13
TXO4: J5.13, U13.13
TXO5: J6.13, U16.13
VCC: C3.1, C4.A, C5.A, C6.1, J3.72, J3.74, U2.4
VCC1: C11.1, C12.1, C13.A, C14.A, J1.72, J1.74, U6.4
VCC2: C20.1, C21.1, C22.A, C23.A, J2.72, J2.74, U9.4
VCC3: C29.1, C30.1, C31.A, C32.A, J4.72, J4.74, U12.4
VCC4: C38.1, C39.1, C40.A, C41.A, J5.72, J5.74, U15.4
VCC5: C47.1, C48.1, C49.A, C50.A, J6.72, J6.74, U18.4
VIN: C1.1, C2.1, C8.1, C9.1, U1.2, U1.39, U1.41, U1.52, U2.1
VIN1: C10.1, C16.1, C17.1, C18.1, U4.2, U4.39, U4.41, U4.52, U6.1
VIN2: C19.1, C25.1, C26.1, C27.1, U7.2, U7.39, U7.41, U7.52, U9.1
VIN3: C28.1, C34.1, C35.1, C36.1, U10.2, U10.39, U10.41, U10.52, U12.1
VIN4: C37.1, C43.1, C44.1, C45.1, U13.2, U13.39, U13.41, U13.52, U15.1
VIN5: C46.1, C52.1, C53.1, C54.1, U16.2, U16.39, U16.41, U16.52, U18.1

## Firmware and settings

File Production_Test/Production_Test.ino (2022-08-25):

/*

  Production Test Code for the:
  SparkX Satellite Transceiver Function Board - Swarm M138 (SPX-20107)
  https://www.sparkfun.com/products/20107
  https://github.com/sparkfunX/Satellite_Transceiver_Function_Board__Swarm_M138

  Hardware Required:

  * A Swarm M138 modem - taken from: Satellite Transceiver Breakout - Swarm M138: https://www.sparkfun.com/products/19236
  * SparkFun MicroMod Main Board - Double: https://www.sparkfun.com/products/18576
  * SparkFun MicroMod ESP32 Processor: https://www.sparkfun.com/products/16781
  * USB Cable

  Setup:

  * Install the ESP32 Processor Board in the Main Board - Double
  * Set the ALT_PWR_EN0 jumper to G5<->PWR_EN0
  * Select the ESP32 Arduino \ SparkFun ESP32 MicroMod processor
  * Connect the Main Board - Double to your computer via USB
  * Upload this sketch onto the ESP32
  * Open the Serial Monitor at 115200 baud to see the output
  
  Test Procedure:

  * Insert the Swarm M138 modem into the Function Board. No need to screw it down
  * Insert the Function Board into the Main Board Slot 0. No need to screw it down. Just hold both boards down with your finger
  * This code:
    * Powers up the M138 modem via the PWR_EN pin
    * Begins serial communication with the modem
    * Checks the firmware version
    * Checks that the GPIO1 pin can be pulled high and low
    * Tells the modem to powerOff (to avoid weirdness)
    * Waits until the modem is disconnected
 
 */

#include <SparkFun_Swarm_Satellite_Arduino_Library.h> //Click here to get the library:  http://librarymanager/All#SparkFun_Swarm_Satellite

SWARM_M138 mySwarm;
#define swarmSerial Serial1 // Use Serial1 to communicate with the modem

// Swarm Satellite Transceiver MicroMod Function Board:
// Uncomment and adapt a line to match your Main Board and Processor configuration:
#define swarmPowerEnablePin G5 // MicroMod Main Board Double (DEV-18576) : Slot 0 with the ALT_PWR_EN0 set to G5<->PWR_EN0
#define swarmGPIO1pin D0 // MicroMod Main Board Double (DEV-18576) : Slot 0

void setup()
{
  //mySwarm.enableDebugging(); // Uncomment this line to enable debug messages on Serial

  delay(2000);
  
  Serial.begin(115200);
  while (!Serial)
    ; // Wait for the user to open the Serial console
  Serial.println(F("Swarm Satellite Function Board - Test Procedure"));
  Serial.println();

  pinMode(LED_BUILTIN, OUTPUT);
  digitalWrite(LED_BUILTIN, LOW); // Turn the LED off

  pinMode(swarmGPIO1pin, INPUT_PULLUP); // Use the pull-up to indicate when the board has been removed

  pinMode(swarmPowerEnablePin, OUTPUT);
  digitalWrite(swarmPowerEnablePin, HIGH); // Enable the high-side power switch
}

void loop()
{
  digitalWrite(LED_BUILTIN, LOW); // Turn the LED off
  
  bool modemBegun = mySwarm.begin(swarmSerial); // Begin communication with the modem

  int beginTries = 0;
  
  while (!modemBegun) // If the begin failed, keep trying to begin communication with the modem
  {
    if (beginTries < 10)
      Serial.println(F("Could not communicate with the modem. It may still be booting..."));
    else
      Serial.println(F("Could not communicate with the modem. Check the M.2 gold finger alignment..."));
    delay(1000);
    modemBegun = mySwarm.begin(swarmSerial);
    beginTries++;
  }

  char firmwareVersion[SWARM_M138_MEM_ALLOC_FV]; // Create storage for the configuration settings

  if (mySwarm.getFirmwareVersion(firmwareVersion) == SWARM_M138_SUCCESS) // Get the firmware version
  {
    Serial.print(F("Modem found! The firmware version is: "));
    Serial.println(firmwareVersion);

    delay(100);
    
    bool keepGoing = (mySwarm.setGPIO1Mode(SWARM_M138_GPIO1_OUTPUT_HIGH) == SWARM_M138_SUCCESS); // Set GPIO1 high

    if (keepGoing)
    {
      delay(100);

      keepGoing = (digitalRead(swarmGPIO1pin) == HIGH); // Check GPIO1 is high

      if (keepGoing)
      {
        delay(100);

        keepGoing = (mySwarm.setGPIO1Mode(SWARM_M138_GPIO1_OUTPUT_LOW) == SWARM_M138_SUCCESS); // Set GPIO1 low

        if (keepGoing)
        {
          delay(100);

          keepGoing = (digitalRead(swarmGPIO1pin) == LOW); // Check GPIO1 is low

          if (keepGoing)
          {
            Serial.println(F("TEST PASSED!"));
            digitalWrite(LED_BUILTIN, HIGH); // Turn the LED on

            delay(100);

            Serial.print(F("Telling the modem to power off...: "));

            keepGoing = (mySwarm.powerOff() == SWARM_M138_SUCCESS); // Modem Power Off

            if (keepGoing)
              Serial.print(F("powerOff was successful! Remove this board and insert the next one"));
            else
              Serial.print(F("powerOff FAILED! Remove this board and re-insert it for a re-test"));

            while (digitalRead(swarmGPIO1pin) == LOW)
            {
              delay(1000);
              Serial.print(F("."));
            }

            Serial.println();
            Serial.println(F("Ready for the next board..."));
          }
          else
          {
            Serial.println(F("TEST FAILED! GPIO1 is high when it should be low. (Possible dry joint on GPIO1?)"));
            delay(1000);
          }
        }
        else
        {
          Serial.println(F("TEST FAILED! Could not set the GPIO1 pin mode to SWARM_M138_GPIO1_OUTPUT_LOW. (Possible TXI/RXO pin error?)"));                
          delay(1000);
        }
      }
      else
      {
        Serial.println(F("TEST FAILED! GPIO1 is low when it should be high. (Possible dry joint on GPIO1?)"));          
        delay(1000);
      }
    }
    else
    {
      Serial.println(F("TEST FAILED! Could not set the GPIO1 pin mode to SWARM_M138_GPIO1_OUTPUT_HIGH. (Possible TXO/RXI pin error?)"));    
      delay(1000);
    }
  }
  else
  {
    Serial.println(F("TEST FAILED! Could not read the firmware version. (Possible TXO/RXI pin error?)"));
    delay(1000);
  }
}

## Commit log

2022-05-23 x01 PCB
    [Satellite_Transceiver_Function_Board__Swarm_M138-Panel.GBL, Satellite_Transceiver_Function_Board__Swarm_M138-Panel.GBO, Satellite_Transceiver_Function_Board__S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]
2022-07-22 x04 PCB
    [Satellite_Transceiver_Function_Board__Swarm_M138-Panel.brd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]

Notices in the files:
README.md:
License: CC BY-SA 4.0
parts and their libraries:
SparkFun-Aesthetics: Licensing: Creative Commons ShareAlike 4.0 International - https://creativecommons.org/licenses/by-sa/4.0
